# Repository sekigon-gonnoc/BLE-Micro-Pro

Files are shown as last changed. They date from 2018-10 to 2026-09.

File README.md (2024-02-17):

# BLE-Micro-Pro



BLE Micro ProはPro Microとの互換性を意識した、nrf52840モジュール搭載のブレークアウトボードです。主に自作キーボードでの使用を想定して設計しています。Pro Microを使用した自作キーボードに取り付けてQMKベースの専用ファームウェアを書き込むことで、USB/BLE5の両方に対応させることができます。  

**質問等は [Self Made Keyboard in Japan の Discord](https://discordapp.com/invite/zXCss8T) #mon-shin🔰 (トラブルシューティング) または #ble-micro-pro（開発関係の質問）チャンネルまで。**
**質問の前に過去ログを参照してください**

## 販売リンク

[BOOTH](https://nogikes.booth.pm/items/1177319)  
[遊舎工房](https://yushakobo.jp/shop/ble-micro-pro/)

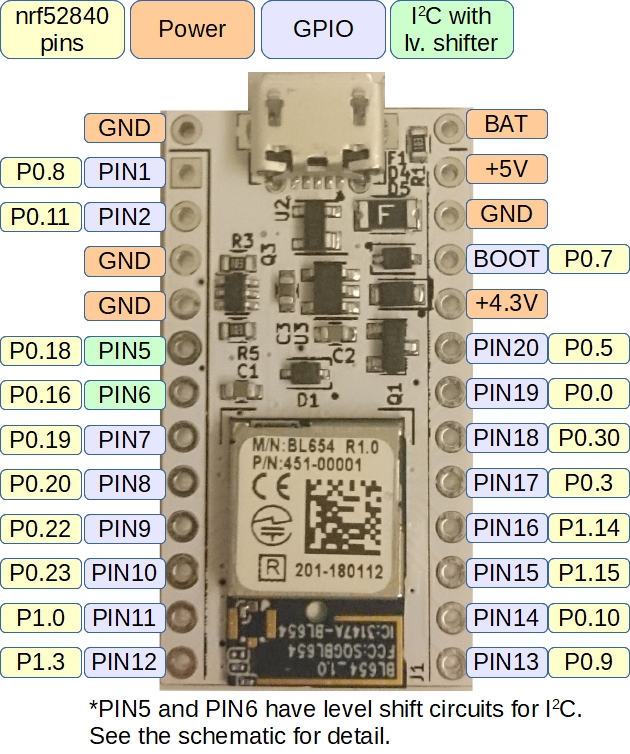
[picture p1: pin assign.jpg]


## 使用上の注意点

Pro Microとの互換性を意識して設計されていますが、以下の点にご注意ください。

- 入出力は3.3Vです。ただし、5・6番ピン(SDA・SCL)のみFETによるレベルシフト回路を実装しています。

- RAWピンの最大電圧は5Vです。

## 接続確認済みデバイス

Windows 10, Androidとの接続を確認しています。使用する機器との相性や使用環境によっては接続が不安定になることがあります。

## 使い方(ハードウェア編)

USBコネクタの横にあるBATピンから、あるいはUSBコネクタ、RAWピン、VCCピンから電源供給できます。

- BATピン (1.7V--3.6V)
- RAW, VCC (3V--5V)
  - ただし、RAW, VCC >= BAT

コンスルーに対応しているため、はんだ付けせずに基板に取り付けることも可能です。

21番ピンは5Vをダイオードで電圧降下させて4.3Vにしています。これは、WS2812などのシリアルLEDを3.3Vの信号で光らせるためです。
Helixなど24番ピンと21番ピンをショートさせているPCBの場合は、24番ピンのピンヘッダを抜き去ることでLEDが光るようになります。
LEDの電源を24番ピンからしか取っていないキーボードの場合は、はんだ付けをして21番ピンから電源を取るように改造してください。
前述のようにダイオードを挟んでいるので21・24番ピンがショートしていても壊れません。

ブートローダー書き込み済みの場合、BOOTピンをGNDに落としながら起動、あるいはファームウェアから呼び出すことでUSB経由でのファームウェアの書き込みができます。

ブートローダーを使わない場合は裏面に露出したパッドからSWDでファームウェアを書き込みます。

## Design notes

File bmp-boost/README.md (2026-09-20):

# BMP Boost

## 概要

BMP Boostは、DC-DC昇圧コンバータを搭載したnRF52開発ボードです。電池一本（0.7V以上）で動作可能で、キーボードやその他の低消費電力ワイヤレスプロジェクト向けに設計されています。

ZMK FirmwareやBLE Micro Pro用のファームウェアで動作します。

- [BOOTH](https://nogikes.booth.pm/items/1177319)
- [遊舎工房](https://shop.yushakobo.jp/products/10737)

## 特徴

- DC-DC昇圧コンバータ内蔵で電池一本（0.7V～）から動作可能
- ZMKまたはBLE Micro Pro用のQMKで動作可能
- 追加IOが必要な場合は、コンスルーのピンを差し替えて一部をハーフピッチにして拡張可能（ZMKのみ）

## ピン配置

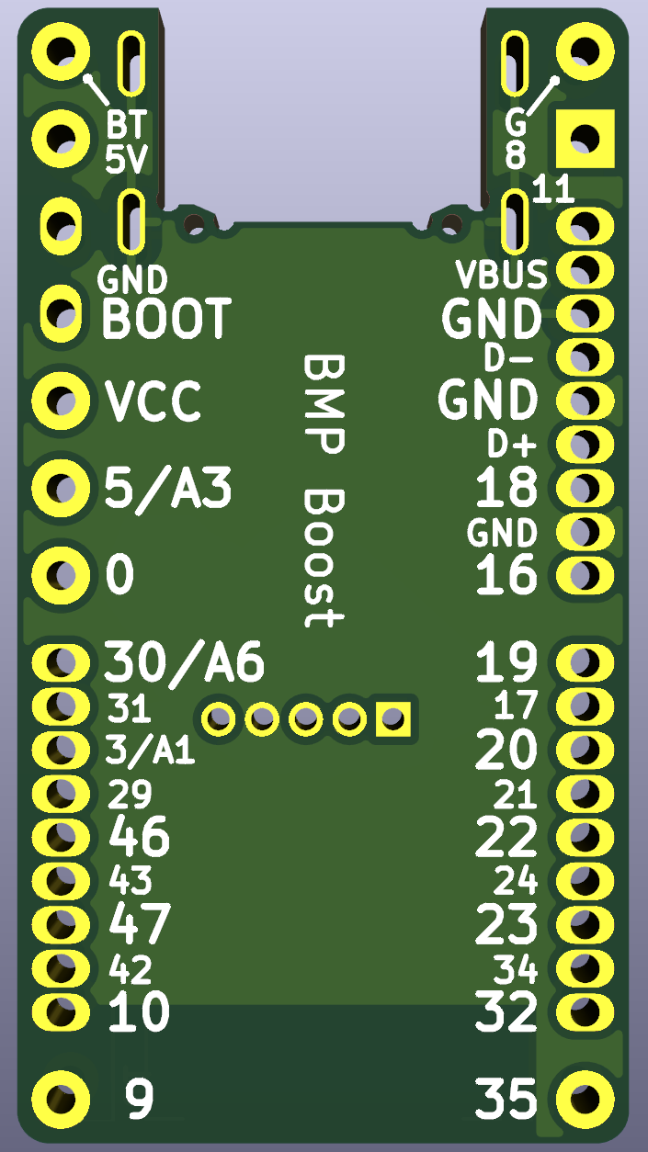
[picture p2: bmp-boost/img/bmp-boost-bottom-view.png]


### 電源コネクタ

| ラベル | 機能 |
| --- | --- |
| BT | 電源入力(0.7~3.3V)、AIN4で電圧測定可能 |
| G | 電源入力GND |

### Pro Micro互換コネクタ

| ピン番号 | ラベル | GPIO番号 | 機能 |
| --- | --- | --- | --- |
| 1 | 8 | P0.08 | GPIO |
| 2 | 11 | P0.11 | GPIO |
| 3 | GND | | GND |
| 4 | GND | | GND |
| 5 | 18 | P0.18 | GPIO |
| 6 | 16 | P0.16 | GPIO |
| 7 | 19 | P0.19 | GPIO |
| 8 | 20 | P0.20 | GPIO |
| 9 | 22 | P0.22 | GPIO |
| 10 | 23 | P0.23 | GPIO |
| 11 | 32 | P1.00 | GPIO |
| 12 | 35 | P1.03 | GPIO |
| 13 | 9 | P0.09 | GPIO |
| 14 | 10 | P0.10 | GPIO |
| 15 | 47 | P1.15 | GPIO |
| 16 | 46 | P1.14 | GPIO |
| 17 | 3/A1 | P0.03 | GPIO/AIN1 |
| 18 | 30/A6  | P0.30 | GPIO/AIN6 |
| 19 | 0 | P0.00 | GPIO |
| 20 | 5/A3 | P0.05 | GPIO/AIN3 |
| 21 | VCC | | VCC出力(約2.4V *1) |
| 22 | BOOT | | GNDに落として電源を入れるとブートローダを起動 |
| 23 | GND | | GND |
| 24 | 5V | | 電源入出力(5V) |

\*1 VCC出力にLED（WS2812など）が接続されていると消費電力が著しく増加します。
LEDを実装しないか、実装してしまっている場合はコンスルーのピンを抜いて接続しないようにしてください。
また、起動電流が大きいデバイスを接続している場合、昇圧動作がうまく始まらない場合があります。

### 追加IO

| ラベル | GPIO番号 | 機能 |
| --- | --- | --- |
| VBUS | | USB電源 |
| D- | | USBのD- |
| D+ | | USBのD+ |
| 17 | P0.17 | GPIO |
| 21 | P0.21 | GPIO |
| 24 | P0.24 | GPIO |
| 34 | P1.02 | GPIO |
| 42 | P1.10 | GPIO |
| 43 | P1.11 | GPIO |
| 29 | P0.29 | GPIO |
| 31 | P0.31 | GPIO |

## ZMK用コンポーネント

- [zmk-component-bmp-boost](https://github.com/sekigon-gonnoc/zmk-component-bmp-boost)
- [QMK用のinfo.jsonをZMK用の設定に変更するツール](https://sekigon-gonnoc.github.io/bmp-qmk-zmk-converter/)
  - 変換結果が正しいとは限らないので適宜修正してください

## 注意事項

- BMPと違いI2Cのレベル変換機能はありません。
- BMPとは電源ピン（VCC）の機能が異なります。
- 仕様等は予告なく変更となる場合があります。

## BMP Boost用拡張ボード

### bmp-boost-extender

[KiCADプロジェクトデータ](./bmp-boost-extender/)

追加IOポートを利用してBMP Boostの背面に搭載できる単四電池基板です。
オプションとしてFFC変換基板を取り付けることもできます。

|  |  |
| --- | --- |
|  |  |

#### デバイスツリーの例

オプションのFFC変換基板を使用して[paw3222センサ](https://github.com/sekigon-gonnoc/small-mouse-sensor-module)と接続する場合は下記をデバイスツリーに追加してください。

```dts
&pinctrl {
    spi0_default: spi0_default {
        group1 {
            psels = <NRF_PSEL(SPIM_SCK, 0, 17)>,
                <NRF_PSEL(SPIM_MOSI, 0, 21)>,
                <NRF_PSEL(SPIM_MISO, 0, 21)>;
        };
    };

    spi0_sleep: spi0_sleep {
        group1 {
            psels = <NRF_PSEL(SPIM_SCK, 0, 17)>,
                <NRF_PSEL(SPIM_MOSI, 0, 21)>,
                <NRF_PSEL(SPIM_MISO, 0, 21)>;
            low-power-enable;
        };
    };
}

&spi0 {
    status = "okay";
    compatible = "nordic,nrf-spim";
    pinctrl-0 = <&spi0_default>;
    pinctrl-1 = <&spi0_sleep>;
    pinctrl-names = "default", "sleep";
    cs-gpios = <&gpio0 31 GPIO_ACTIVE_LOW>;

    trackball: trackball@0 {
        status = "okay";
        compatible = "pixart,paw3222";
        reg = <0>;
        spi-max-frequency = <2000000>;
        irq-gpios = <&gpio0 29 GPIO_ACTIVE_LOW>;
        power-gpios = <&gpio0 24 (GPIO_ACTIVE_HIGH | NRF_GPIO_DRIVE_H1)>;
    };
};
```

KiCadで作成した基板の設計データは[こちら](bmp-boost-extender/)

### BMP Boost Extender Mini

[リポジトリ](https://github.com/ngsyst/bmp_boost_extender_mini)

ngsystさんが公開している小型の拡張基板です。FFCコネクタがハンダ付けされておりトラックボールやトラックパッドモジュール、エンコーダと接続可能です。

### bmp-boost-led-extender

[KiCADプロジェクトデータ](./bmp-boost-led-extender/)

緑・黄・赤の三色のLEDを追加する拡張基板です。本基板もFFCケーブルで拡張モジュールを接続できます。

#### デバイスツリーの例

[torabo-tsuki LP用のスニペット](https://github.com/sekigon-gonnoc/zmk-keyboard-torabo-tsuki-lp/tree/master/snippets/led-plus)

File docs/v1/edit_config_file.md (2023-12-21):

# 新しいキーボード用の設定を作成する

## config.jsonの説明

|キー|値|内容|
|---|---|---|
|version|3|config構造体のバージョン。 ブートローダ内の構造体の定義が変わらない限り変えない|
|pid, vid|string|16進数のPIDとVID|
|name|string||
|manufacture|string||
|rows|int|マトリクスの列数|
|cols|int|マトリクスの行数|
|device_rows|int|分割型の場合は片手分のマトリクスの列数。 一体型の場合rowsと同じにする|
|device_cols|int|分割型の場合は片手分のマトリクスの行数。 一体型の場合colsと同じにする|
|diode_direction|0~5|マトリクスの構成をあらわす。詳細は下記|
|row_pins|int array|マトリクスの行ピン。番号はPINxxに対応|
|col_pins|int array|マトリクスの列ピン。番号はPINxxに対応|
|mode|SPLIT_MASTER, SPLIT_SLAVE, SINGLE|分割マスター、分割スレーブ、一体型|
|startup|int|電源が入ったタイミングでBLEのアドバタイズを実行するかどうか。 [0]は実行しない、[1]で実行する。|
|led->pin|int array|LED(ws2812系)のピン。番号はPINxxに対応|
|led->num|int|LEDの数|
|reserved|uint8_t[8]|予約領域。現時点では[1]はインジケータLEDのピン設定、[2]はオートスリープの時間設定に使用|

### 通信間隔の設定

無線接続時に遅延を感じる場合はperipheral, centralの max_interval, min_intervalを小さくしてください。最小値は10msで、5ms刻みで変更できます  
また、OSのBLEに関する省電力設定も確認してみてください

### マトリクスの構成

#### diode_direction
 
|数値|構成|説明
|---|---|---|
|0|COL2ROW|QMKと同じ|
|1|ROW2COL|QMKと同じ|
|2|COL2ROW with LPME|master側がCOL2ROWでスレーブ側にはLPMEを搭載|
|3|ROW2COL with LPME|master側がROW2COLでスレーブ側にはLPMEを搭載|
|4|COL2ROW2COL|duplex-matrix。COL2ROWでスキャンしたあとROW2COLでスキャンする。modeがSINGLEのときのみ対応|
|5|ROW2COL2ROW|duplex-matrix。ROW2COLでスキャンしたあとCOL2ROWでスキャンする。modeがSINGLEのときのみ対応|

#### row_pins, col_pins
  -  COL2ROW, ROW2COLの場合: 通常のマトリクスの設定。device_rows/colsに指定したのと同じ数だけピンを設定する
  -  with LPMEの場合: LPMEを使ったマトリクスの設定。BLE Micro Proが制御するマトリクスのピン設定に続けて、LPMEが制御するマトリクスのピン設定を書く。合計でrows/colsに設定したのと同じ数だけピンを設定する
  -  duplex matrixの場合: 最初にスキャンする方向に合わせてrow_pins, col_pinsを設定する。device_rows, device_colsにはrow_pins, col_pinsの要素数を指定する。rowsにはdevice_rowsの2倍の値を、colsにはdevice_colsと同じ値を設定する



### オートスリープ

電池駆動時に一定時間無入力の状態が続くと自動的にスリープします。

スリープまでの時間は`config.reserve[2]*10min`です。

オートスリープを無効にするには`reserve[2]`に0を指定してください。

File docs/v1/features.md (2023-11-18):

# 特徴/機能一覧

## USB/BLEでの接続
- BLE Micro Proを1台使用した一体型キーボードの完全無線化
  - Naked60BMPのような一体型キーボードの場合、Pro MicroをBLE Micro Proに置き換えることで無線化できます
  - 消費電力はマスター側で\~100uAで、300mAhの電池を使うと3000時間もつ計算です

- BLE Micro Proを2台使用した分割キーボードの完全無線化
  - HelixやErgo42のような分割型の自作キーボードを完全無線化できます
  - 消費電力はマスター側で\~300uA、スレーブ側で\~100uA程度で、300mAhの電池を使うと1000時間もつ計算です

- BLE Micro ProとLPME-IOを使用した部分無線化
  - 分割キーボードの片方にBLE Micro Proを、もう一方にLPME-IOを搭載することで左右の通信は有線、デバイスとの通信は無線という構成が実現できます
    - LPME-IOを使用するにはキーボード基板がI2Cによる左右の通信に対応している必要があります 

## プログラミングレスでのファームウェア更新・設定変更・キーマップ書き換え
  - BLE Micro Proをパソコンに接続するとUSBドライブとして認識され、設定ファイルを書き込むことでキーボードの設定やキーマップを書きかえることができます。そのため、取り付けるキーボードを変えたりキーマップを変えたりするときにプログラミングしなおす必要がありません。
  - キーマップはRemap, Vialを使って変更できます。Vialを使うことでTapping Termなどの設定を変更したり、コンボ・タップダンス・オーバーライドを設定することもできます
  - ブートローダー起動時もUSBドライブとして認識され、ファームウェアをドラッグアンドドロップすることでアップデートできます
  - セキュリティの都合等でUSBドライブとして認識されると困る場合には機能を無効化できます

## その他

- 穴径がコンスルーに対応しているため、コンスルーを使う場合はハンダ付け不要
- BLEの接続状況を示すためのインジケータLED（ディスクリートのLEDによる）
- 無線接続中、一定時間の間に入力がないと自動的に省電力モードに移行（無効化可）

## QMKの機能対応状況
|機能|対応|補足|
|--|--|--|
|キーボード|✔|
|マウス|✔|
|System/Consumer(音量など)|✔|
|エンコーダ|✔|
|VIA(Remap)|✔||
|VIAL|✔||
|Console|✔|HIDではなくシリアルポートによる実装。print/dprintに加えて[CLI](cli.md)を提供|
|Raw|✔|
|LED|✔|USB電源駆動時のみ。左右同期も実装済み|
|OLED|✔|
|eeprom|✔||
|SPI|✔|
|I2C|✔|
|Analog|✔|17,18,20番ピンのみ|
|Audio|❌|
|NKRO|❌|
|PS/2|❌|
|USART|❌|

## ハードウェア仕様

### 電源
以下の二系統から供給可能。RAW, VCCからの供給がBATより優先される
  - BAT (1.7V--3.6V)
  - RAW or VCC (3V--5V)
    - ただし、RAW, VCC >= BATのときのみ

### 入出力
  - 電源電圧か3.3Vの低い方 (**5Vトレラントではありません**)
  - 5・6番ピン(Pro MicroのSDA・SCL)のみFETによるレベルシフト回路を実装

### 接続確認済みデバイス

- Windows, Androidとの接続を確認しています。ただし、使用するbluetoothアダプタによっては接続が不安定になることがあります。

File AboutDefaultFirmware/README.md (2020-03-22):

# BLE Micro Pro 標準ファームウェア (beta版)

## 特徴
 キーボードやキーマップごとにファームウェアをビルドし直すのではなく、マトリクスの構造やキーマップといった情報をBLE Micro Pro上のファイルを編集して変更します

 BLE Micro Proをパソコンに繋ぐとマスストレージデバイスとして認識され、設定ファイルを編集できます

 キーマップの書き換えには[QMK Configurator](https://config.qmk.fm)が生成したjsonファイルも使用できます

 
 
## 制約 
 defineで切り替えるタイプのQMKの設定を変更したい場合や、キーマップにカスタムキーコードなどを追加したい場合はファームウェアのビルド/書き込みが必要です

 その場合でもビルド環境の用意は以前より簡単になっています

## 使い方 
- [Getting started](doc/getting_started.md)
- [ビルド方法](doc/build_bmp_qmk_firmware.md)
- [Command Line Interface](doc/cli.md)
- [キーボード開発者向け情報](doc/define_new_keyboard.md)

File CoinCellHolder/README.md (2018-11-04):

# CR1632基板キット

CR1632を二個のせられます。並列的に繋いでいるので、1個の電池のみで動かすことも出来ます。

## 組み立て上の注意点

- コイン電池ホルダの突起を基板側のシルクに合わせる

- 電池ホルダ間のクリアランスが狭いのでショートしないようにする
- 電池ホルダの足を折り曲げると背が低くなる
- ダイオードの向きに注意(ダイオードのカソード(ラインが入ってるほう)がシルクのマーク側)
- 電源出力のマイナス側は出っ張らないようにする(電池の取り付け・取り外しができなくなる)
- 他の基板と接触する部分(作例だと裏面)はテープなどで絶縁する







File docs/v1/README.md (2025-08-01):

# BLE Micro Pro

BLE Micro ProはPro Microとの互換性を意識した、nrf52840モジュール搭載のブレークアウトボードです。主に自作キーボードでの使用を想定して設計しています。Pro Microを使用した自作キーボードに取り付けてQMKベースの専用ファームウェアを書き込むことで、USB/BLE5の両方に対応させることができます。  

**こちらは最新版ファームウェア(v1)の説明です。最新版では設定ファイルの形式が変更になりました。Vialにも対応しています。**

**BMP BoostのハードウェアやZMKで使用する方法については[こちら](https://github.com/sekigon-gonnoc/BLE-Micro-Pro/tree/master/bmp-boost)をご確認ください。**

[QMK用のinfo.jsonをZMK用の設定に変更するツール](https://sekigon-gonnoc.github.io/bmp-qmk-zmk-converter/)
  - 変換結果が正しいとは限らないので適宜修正してください

## 販売リンク

[BOOTH](https://nogikes.booth.pm/items/1177319)  
[遊舎工房](https://yushakobo.jp/shop/ble-micro-pro/)

## 特徴

- BLEでの無線接続
  - BLE Micro Proを2台使用した分割キーボードの完全無線化
  - BLE Micro ProとLPME-IOを使用した部分無線化
- USBでの有線接続
- プログラミングレスでのファームウェア更新・設定変更・キーマップ書き換え

## スタートガイド

- [買ってきた自作キーボードキットを無線化したい](getting_started.md)
  - 遊舎工房やBOOTHで購入したキットを無線化する場合はこちら
  - Pro Microを使用しているキットを無線化できます
- [BLE Micro Proに対応したキーボードを設計したい](design_guide.md)
  - 自分でキーボードを設計するときの注意点などをまとめています

## 困ったときは

- [よくある質問](FAQ.md)
- そのほかの質問等は [Self Made Keyboard in Japan の Discord](https://discordapp.com/invite/zXCss8T)
#mon-shin🔰 (トラブルシューティング) または #ble-micro-pro（開発関係の質問）チャンネルまで。過去ログを検索すると役立つ情報があるかもしれません。

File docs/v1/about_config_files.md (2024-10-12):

# 設定について

- [BLE Miro Proを更新して設定ファイルを書き込む手順](#ble-miro-proを更新して設定ファイルを書き込む手順)
  - [bmp-vial対応の設定ファイルを用意する](#bmp-vial対応の設定ファイルを用意する)
  - [BLE Micro Proに設定ファイルを書き込む](#ble-micro-proに設定ファイルを書き込む)
- [BLE Miro Pro Web Configuratorに登録するための手順](#ble-miro-pro-web-configuratorに登録するための手順)
  - [vial.jsonとconfig.jsonの用意](#vialjsonとconfigjsonの用意)
  - [デフォルトキーマップ用binファイルを用意する](#デフォルトキーマップ用binファイルを用意する)
  - [2種類のjsonファイルとデフォルトキーマップ用binファイルを登録する](#2種類のjsonファイルとデフォルトキーマップ用binファイルを登録する)

## BLE Miro Proを更新して設定ファイルを書き込む手順

### bmp-vial対応の設定ファイルを用意する

設定ファイルは2種類のjsonファイルと、jsonから生成される1つのbinファイルがあります。
これらの設定ファイルは[bmp-vial-config-generator](https://sekigon-gonnoc.github.io/bmp-vial-config-generator/)を利用することでQMKのinfo.jsonから変換できます。そのため、すでにPro Micro用のファームウェアが用意されていれば、単純な変換作業のみでBLE Micro Pro用の設定も用意できます。

* vial用jsonファイル(vial.json)
  * vial用の設定ファイルです
* config用jsonファイル(config.json)
  * BLE Micro Pro用の設定ファイルです。従来とは一部の項目が変わっています
* 書き込み用binファイル(config.bin)
  * vial.jsonとconfig.jsonから生成された書き込み用のバイナリファイルです

1. 左側のテキストボックスにQMKのinfo.jsonを記入する
   1. QMK公式のリポジトリにinfo.jsonが存在する場合はテキストボックス下部にあるリストから選択できます。
   1. info.jsonの中にはmatrixのピンと配置の情報が必要です。これらの情報がconfig.hやLAYOUTマクロに記入されている古いファームウェアでは`qmk info -kb <keyboard> -f json`コマンドを使用するとinfo.jsonを生成できる場合があります。
2. 左下の`Generate`ボタンをクリックしてvial.jsonとconfig.jsonを生成する
   1. 自動生成されたvial.jsonでは内容が不十分な場合はテキストボックスの中身を書き換えてください
3. 中央下の`Append BMP custom keycodes`ボタンをクリックして、BLE Micro Pro用のカスタムキーコードリストをvial.jsonに追加する
4. 分割キーボードの場合は右下のリストからconfig.jsonの対象(master, slave, lpme)を選択する
   1. 自動生成されたconfig.jsonでは内容が不十分な場合はテキストボックスの中身を書き換えてください。通常のマトリクスであればinfo.jsonからの自動変換で十分な場合が多いですが、duplex-matrixは修正が必要な場合があります。→[config.jsonの説明](edit_config_file.md)
5. `Download config.bin`ボタンをクリックしてconfig.binを生成・ダウンロードする

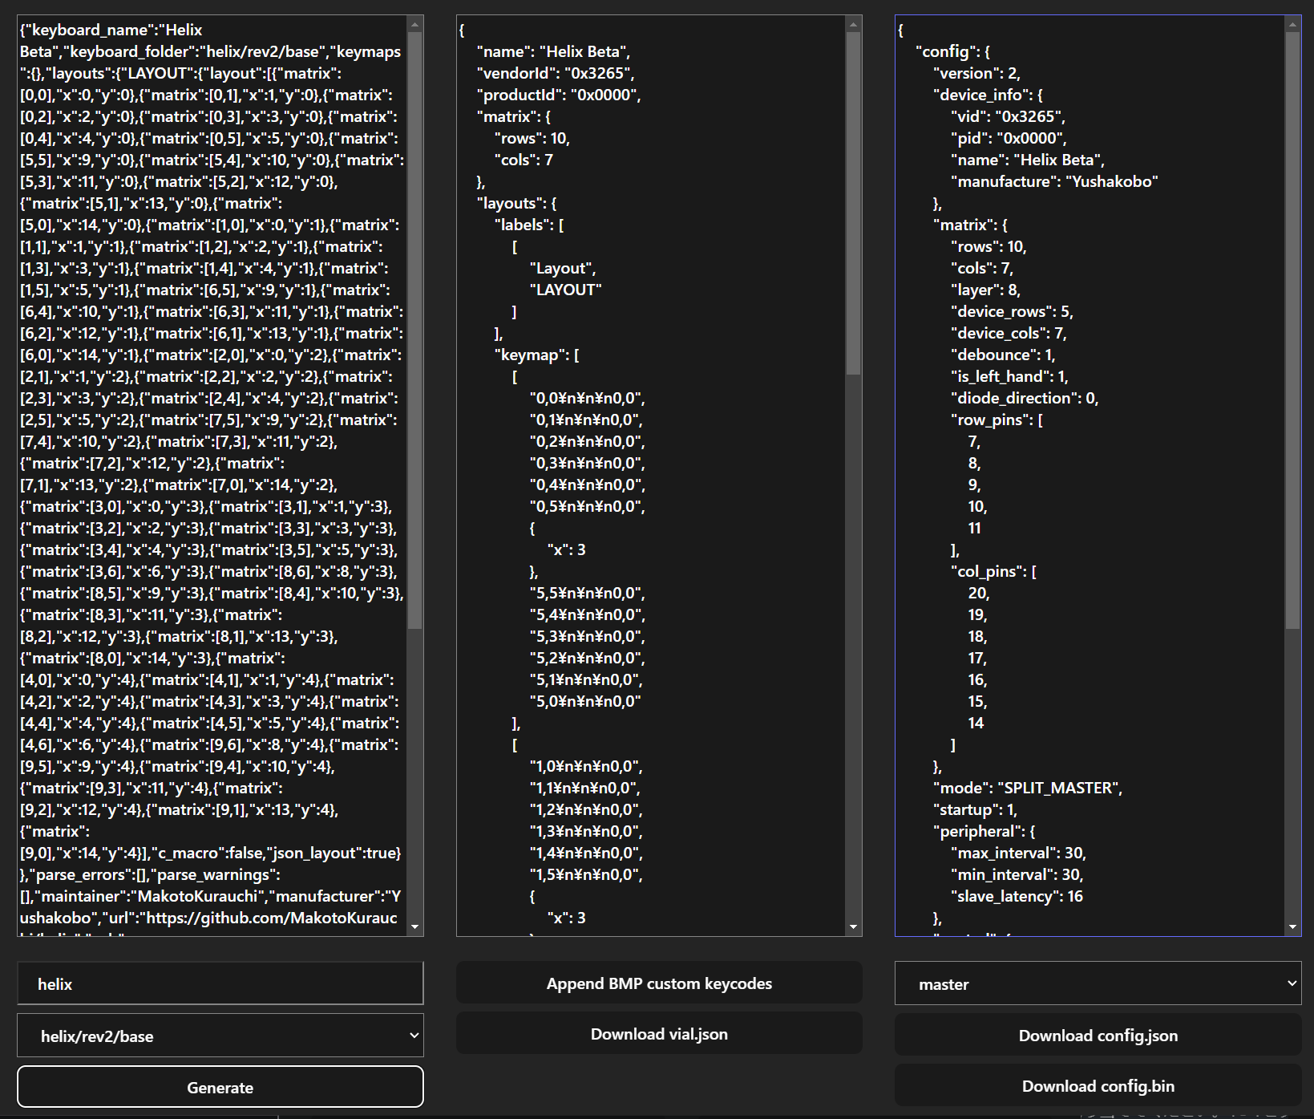
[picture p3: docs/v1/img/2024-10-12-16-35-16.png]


### BLE Micro Proに設定ファイルを書き込む 

マスストレージ経由で書き込む場合は下記の手順で作業してください。

1. BLE Micro Proのアプリケーションが起動していることを確認する
   1. マスストレージとして認識されているBLE Miro Proを開き、中にCONFIG.BINがあることを確認する
2. 用意したconfig.binをドラッグアンドドロップして書き込む（ファイル名は任意）
3. 書き込み完了後に電源を再投入して、デバイス名が書き込んだキーボードに変わっていることを確認する

[BLE Micro Pro Web Configurator](https://sekigon-gonnoc.github.io/BLE-Micro-Pro-WebConfigurator/)から設定を書き込むこともできます。

* `Edit config`メニューを選択してください。
* キーボードリストから`Upload your own`を選択してください。
* `Update`をクリックするとファイルダイアログが表示されます。作成したbinファイルを選択してください。
* USBデバイスへのアクセスを求めるポップアップが表示されます。
* キーボードを選択して`接続`をクリックすると書き込みが始まります。
  * どのデバイスがBLE Micro Proか分からない場合はUSBケーブルを抜き差ししてデバイス一覧の変化を確認してください。
  * ポップアップにキーボードが表示されない場合はファームウェアの書き込みができていないので、最初のステップからリトライしてください。
* 書き込みが成功したら次のステップに進んでください。
  * 数十秒待っても書き込みが完了しなかったらブラウザをリロードしてUSBケーブルを抜き差してからリトライしてください。

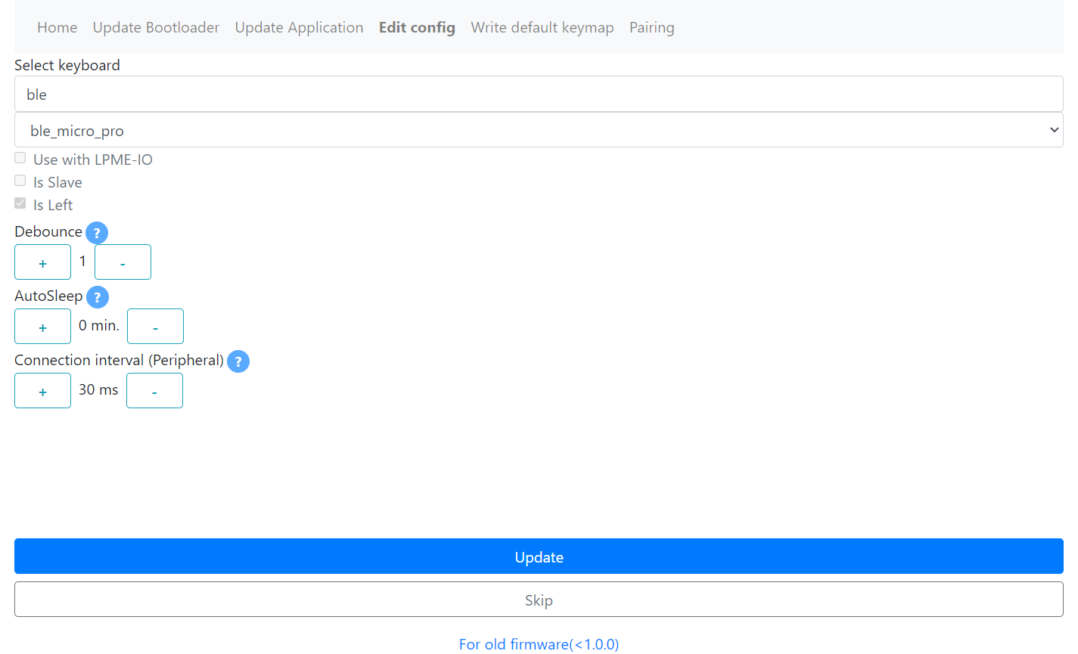
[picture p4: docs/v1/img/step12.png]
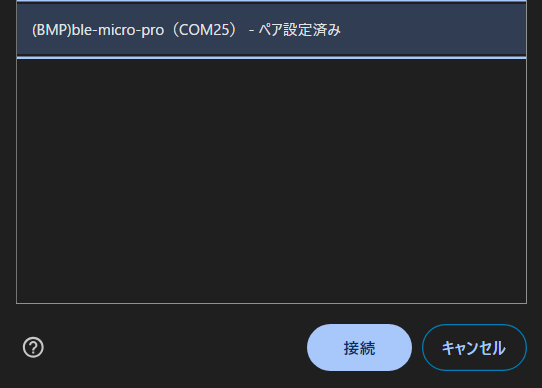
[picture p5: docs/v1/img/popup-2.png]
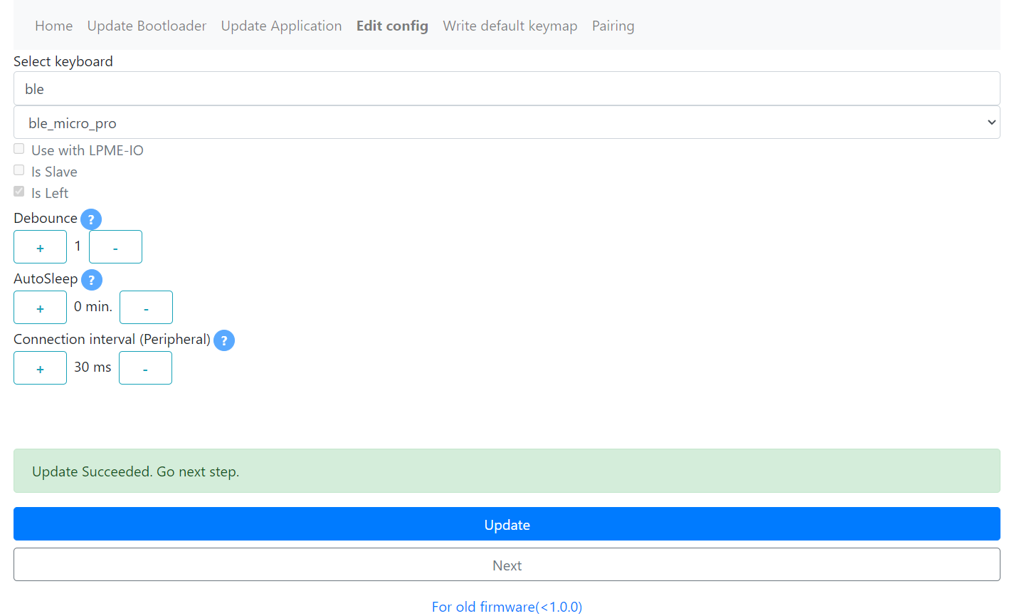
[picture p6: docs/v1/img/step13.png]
|  |  |  |
| --- | --- | --- |

## BLE Miro Pro Web Configuratorに登録するための手順

Vial対応の設定ファイルをBLE Micro Pro Web Configuratorに登録したい方は追加で以下の手順の実施をお願いします。該当キーボードの作者以外の方でもプルリクエストを作成していただいて構いません。

1. [bmp-vial-config-generator](https://sekigon-gonnoc.github.io/bmp-vial-config-generator/)でvial.jsonとconfig.jsonを生成し、ダウンロードする
1. (任意)デフォルトキーマップ用binファイルを用意する
1. 2種類のjsonファイルとデフォルトキーマップ用binファイルを[bmp-vial-config/](https://github.com/sekigon-gonnoc/BLE-Micro-Pro/tree/master/bmp-vial-config)フォルダに保存し、プルリクエストを作成する

### vial.jsonとconfig.jsonの用意

[bmp-vial-config-generator](https://sekigon-gonnoc.github.io/bmp-vial-config-generator/)で設定を作成したら、それぞれの列の下部にある`Download *.json`ボタンをクリックして各jsonファイルをダウンロードしてください。

### デフォルトキーマップ用binファイルを用意する

EEPROMリセット時に反映されるデフォルトキーマップの設定ファイルを用意してください。

1. RemapまたはVialを使ってデフォルトにしたいキーマップをキーボードに書き込む
2. BLE Micro Proのマスストレージを開きEEPROM.BINをPCにコピーする
3. コピーしたEEPROM.BINの名前を変更する
   1. 名前はキーボード設定用のconfig.binに合わせて`<キーボード名>_default.bin`としてください
4. ファイルをBLE Micro Proに書き戻し、EEPROMをリセットしたときに意図通りのキーマップになっていることを確認する

### 2種類のjsonファイルとデフォルトキーマップ用binファイルを登録する

BLE Miro Proのリポジトリの [bmp-vial-config/](https://github.com/sekigon-gonnoc/BLE-Micro-Pro/tree/master/bmp-vial-config)フォルダにvial.json, config.json, default.binファイルを追加してプルリクエストを作成してください。

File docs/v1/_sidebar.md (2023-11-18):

* [はじめに](/)
  * [特徴/機能一覧](features.md)
  * [自作キーボードキットを無線化する](getting_started.md)
  * [無線対応の自作キーボードを設計する](design_guide.md)

* [設定について](about_config_files.md)

* [発展編](advanced.md)
  * [ファームウェアをビルドする](build_firmware.md)
  * [CLIから操作する](cli.md)
  * [セーフモードについて](safemode.md)

* [FAQ](FAQ.md)

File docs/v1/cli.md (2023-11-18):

# CLI

BLE Micro Proに各種のコマンドを命令したり、デバッグメッセージを確認したりできます。

BLE Micro ProのCLIを開くにはTeraTerm・screen・cuなどからシリアルポートを開いてください。

| command | description |
| --- | --- |
| reset | Reset system |
| adv | Start advertising |
| dfu | Jump to bootloader |
| show | Show bonded devices |
| del | Delete bond information |
| help | Show this message |

## adv `<id>`

 id番目のペアリング済みデバイスに向けてアドバタイズを開始します。分割マスター設定の場合、スレーブデバイスのスキャンも開始します。idを指定しない場合はペアリングしていないデバイスも含めすべてのデバイスに向けてアドバタイズを開始します。  
 ペアリング済みデバイス一覧はshowコマンドで確認できます

## show

BLEのペアリング状況(ID, role, MAC)を表示します。

## del `<id>`

id番のデバイスとのペアリングを削除します。別途相手デバイス側に残っているペアリング情報も削除してください  
idを指定しない場合すべてのペアリング情報を削除します

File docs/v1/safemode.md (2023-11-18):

# セーフモードについて

CONFIG.BINの中身が間違っている場合などにBLE Micro Proがセーフモードとして起動することがあります。発生要因は以下のとおりです。

- CONFIG.BINの中身が間違っている
- `BMP_FORCE_SAFE_MODE`フラグを有効にしたファームウェアを書き込んだ
- BLE Micro Pro内部でエラーが一定回数以上発生した

セーフモードで起動すると書き込んだCONFIG.BINの代わりにファームウェアに埋め込まれたデフォルトの設定が使用されます。

セーフモードで起動しているかどうかは[CLI](cli.md)に繋いだときの表示名がキーボード名か、safemodeになっているかで判別できます。

セーフモードから復帰するには一度リセットまたは電源再投入してください。

何度リセットしてもセーフモードになる場合、CONFIG.BINの中身が間違っている可能性があるため、中身を確認して書き換えてください。

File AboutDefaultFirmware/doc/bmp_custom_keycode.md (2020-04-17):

[ドキュメントサイトに移転しました](https://sekigon-gonnoc.github.io/BLE-Micro-Pro)

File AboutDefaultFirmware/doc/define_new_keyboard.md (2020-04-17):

[ドキュメントサイトに移転しました](https://sekigon-gonnoc.github.io/BLE-Micro-Pro)

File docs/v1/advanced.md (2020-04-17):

# 発展編

ファームウェアに機能を追加するために自分でビルドする方法や、トラブル時に役立つ情報をまとめます。

- [ファームウェアをビルドする](build_firmware.md)
- [CLIから操作する](cli.md)
- [セーフモードについて](safemode.md)

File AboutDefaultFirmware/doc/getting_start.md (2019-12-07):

# Getting start
- [Getting start](#getting-start)
  - [ブートローダ・アプリケーションのアップデート](#ブートローダアプリケーションのアップデート)
    - [ブートローダの起動](#ブートローダの起動)
    - [uf2を使ったアップデート](#uf2を使ったアップデート)
    - [nrfutilを使ったアップデート](#nrfutilを使ったアップデート)
      - [nrfutilの準備](#nrfutilの準備)
      - [アップデートの実行](#アップデートの実行)
  - [config.jsonの書き込み](#configjsonの書き込み)
  - [keymap.jsonの設定](#keymapjsonの設定)
  - [tapping_term.jsonの設定](#tapping_termjsonの設定)
  - [config.jsonの設定 (一般ユーザ向け)](#configjsonの設定-一般ユーザ向け)
    - [開発者向け情報](#開発者向け情報)
  - [設定ファイルのアップデート](#設定ファイルのアップデート)
  - [設定ファイルの削除](#設定ファイルの削除)

## ブートローダ・アプリケーションのアップデート
BLE Micro Proはブートローダとアプリケーションファームウェアがセットになって動作します

- アップデートする場合ブートローダとアプリケーションのメジャーバージョン・マイナバージョンを一致させてください。バージョン番号の表記は下記のとおりです。
  ```
    version number: <major>.<minor>.<revision>
  ```

- アップデートはブートローダ -> アプリケーションの順に行ってください。また、アプリケーションをアップデートする前にKEYMAP.JSNなどの設定ファイルのバックアップを取ってください

- [ブートローダ](https://github.com/sekigon-gonnoc/BLE-Micro-Pro/releases)と[コンパイル済みアプリケーション](https://github.com/sekigon-gonnoc/qmk_firmware/releases)はReleaseページから入手できます。  
  - コンパイル済みアプリケーションにはQMKのビルドオプションとしてTAPPING_TERM_PER_KEY, PERMISSIVE_HOLD などが設定してあります。  
  - 最新版のファームウェアを使いたい場合、自分の好きなオプションを設定したい場合やカスタムキーコードを設定したい場合は[自分でビルドする](build_bmp_qmk_firmware.md)必要があります。  
 
### ブートローダの起動
- キーボードのリセットボタンを押しながらUSB接続するとブートローダが起動します

- 既にキーボードとして動作する場合には[CLI](cli.md)からdfuコマンドを送信することでも起動できます  

- v0.4.0以降のQMK for BMPを使用している場合、起動中にリセットスイッチ長押しでも起動します

- v0.2以降のブートローダとそれ以前ではアップデート方法が異なります。バージョンに応じた手順でファームウェアとブートローダをアップデートしてください

  - [マスストレージデバイスとして認識される場合](#uf2を使ったアップデート)

  - [マスストレージデバイスとして認識されないが、シリアルポートとしては認識される場合](#nrfutilを使ったアップデート)
    - どのポートがBLE Micro Proかわからない場合は、起動前後のシリアルポート一覧を比較してください

### uf2を使ったアップデート
拡張子が`.uf2`のファイルを使って書き込みます  
**[ブートローダーv0.2.0, v0.3.0からアップデートする場合はv0.2.1, v0.3.1を経由してください](https://github.com/sekigon-gonnoc/BLE-Micro-Pro/issues/10)**  
nrfutilを使う場合は経由せずに直接アップデートできます

- BLE Micro Proがマスストレージデバイスとして認識され、中に`INFO_UF2.TXT`があることを確認してください。このファイルがない場合、ブートローダの起動に失敗しているので再起動してください
  - v0.4.0以降、ブートローダ起動時のボリュームラベルはBLEMICROPRO、キーボード起動時のボリュームラベルは設定したキーボード名になるので、これで判別することもできます

- アップデートしたいuf2ファイルをコピーするとアップデートが始まります。アップデート中はケーブルを外さないでください

- アップデートが完了すると自動でアンマウントされます

- ブートローダをアップデートした場合、`INFO_UF2.TXT`を開いてアップデート完了を確認してください

- アプリケーションのアップデートの場合は`VERSION.TXT`を開いてアップデート完了を確認してください

ブートローダ、アプリケーションのアップデートが完了したら次の手順は[config.jsonの書き込み](#configjsonの書き込み)です

### nrfutilを使ったアップデート
拡張子が`.zip`のファイルを使って書き込みます

#### nrfutilの準備
書き込みソフトである[nrfutil](https://github.com/NordicSemiconductor/pc-nrfutil)を用意します。

- Windowsの場合  
    nrfutil.exeを[ダウンロード](https://github.com/NordicSemiconductor/pc-nrfutil/releases)してください

- Linux, Macの場合  
    pipでnrfutilをインストールしてください。以前はpython2.x向けでしたが現在はpython3系で動作するようです。
    ```
      pip install --user nrfutil
    ```

#### アップデートの実行
- キーボードのリセットボタンを押しながらUSB接続、またはターミナルソフトからdfuコマンドを送信してから以下を実行します。パッケージ名、ポート名は状況に応じて書き換えてください  
    ```
   nrfutil dfu usb-serial -pkg <パッケージ名>.zip -p <ポート名>
    ```
 
## config.jsonの書き込み
 - BLE Micro ProをPC等にUSBで接続するとマスストレージデバイスとして認識されます  
   アプリケーションが起動している場合は`KEYMAP.JSN`や`CONFIG.JSN`といったファイルが確認できます

 - 使いたいキーボードのconfig.jsonをコピーしてください。[keyboards](../keyboards)フォルダに使いたいキーボードがない場合は[スクリプトを使ってQMKから生成](define_new_keyboard.md)できます

 - コピー完了後、BLE Micro Proを再起動してください

## keymap.jsonの設定
 - [QMK Configurator](https://config.qmk.fm)で生成したkeymap.jsonをそのまま読み込むことができます。

 - keymap.json, tapping_term.jsonは即時反映されるので再起動は必要ありません

 - 認識できる KC_XX はQMK Configurator準拠です  
    `"KC_EXLM", "KC_AT", "KC_HASH"`

 - 書き込み時にはKC_を付けなくても認識されます。読み出し時には自動でKC_が付きます  
    `"KC_A", "A", "a"` 

 - !, @, # などの記号をそのまま書き込むこともできます。`\`, `"` を設定するときはエスケープしてください。  
    `"!", "@", "#", "\\", "\""`

 - USキーボードとJPキーボードでキーコードが違う記号を書き込んだ場合にどちらで解釈されるかはconfig.jsonの設定によります。（例: "@"： USのとき-> KC_AT, JPのとき -> JP_AT) 

 - カスタムキーコードとして[BLE Micro Pro固有のキーコード](bmp_custom_keycode.md)にも対応しています 

 - 自分でファームウェアをビルドしてカスタムキーコードを設定した場合でも辞書を定義しておけば認識できます。ANY(1255)などして数値で直接指定する方法もあります。
 
## tapping_term.jsonの設定
 - get_tapping_term()で返すキーコードとタッピングタームのペアを設定します
 - デフォルトのタッピングタームはKC_NOに設定します
 - KC_NOは一番最後に設定してください
  ```
  {"tapping_term":{
        "LT(1,KC_A)":300,  
        "KC_NO":200,
        }}
  ```

## config.jsonの設定 (一般ユーザ向け)
|キー|値|内容|
|---|---|---|
|debounce|1 ~|debounceの設定。1増やすと17ms伸びる|
|is_left_hand|0 or 1|左手用のとき1|
|mode|SPLIT_MASTER, SPLIT_SLAVE, SINGLE|分割マスター、分割スレーブ、一体型|
|startup|0 or 1|起動時に自動でアドバタイズを開始する場合は1|
|locale|US or JP|英語キーボード or 日本語キーボード|
|use_ascii|0 or 1| 1の場合keymap.jsonの表示内容がQMK準拠ではなく記号になる.<br> 例) KC_EXLM -> KC_!|
|peripheral||マスター、一体型の場合: PC等との接続に使われる設定<br>スレーブの場合: マスターとの接続に使われる設定|
|cetral||マスターの場合のみ: スレーブとの接続に使われる設定|

無線接続時に遅延を感じる場合は peripheral, central の max_interval, min_interval を小さくしてください。最小値は10msで、5ms刻みで変更できます  
また、OSのBLEに関する省電力設定も確認してみてください

### [開発者向け情報](define_new_keyboard.md)

## 設定ファイルのアップデート
  BLE Micro Pro上のファイルを直接編集することもできますが、バックアップの意味も兼ねて一度PC上にコピーしてから編集、転送することを推奨します。
  
## 設定ファイルの削除
  PCから見えているファイルを削除してもBLE Micro Proを再起動すると復活します。完全に削除してデフォルトに戻したい場合は[CLI](cli.md)からremoveコマンドを使ってください。

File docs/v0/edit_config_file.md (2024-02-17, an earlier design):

# 新しいキーボード用の設定を作成する

**このページは旧バージョンのファームウェアについての説明です。最新版ファームウェアの説明は[こちら](../v1/README.md)**

## QMK用の設定から変換する

Pro Micro用のQMKがすでにある場合はその設定を利用してBLE Micro Pro向けの`config.json`を生成できます。
ベースとなるQMKのバージョンに応じて下記のいずれかの方法を使用してください

### QMK公式にマージざれている場合

https://sekigon-gonnoc.github.io/ble-micro-pro-config-generator/

でkeyboardとlayoutを選択してconvertボタンをクリックすると設定が生成されます。

### info.jsonに各種設定を用意している場合

https://sekigon-gonnoc.github.io/ble-micro-pro-config-generator/

のテキストボックスにinfo.jsonの中身を貼り付けて、検出されたlayoutを選択してconvertボタンをクリックすると設定が生成されます。

### config.hに各種設定を用意している場合

[変換スクリプト](https://github.com/sekigon-gonnoc/BLE-Micro-Pro/blob/master/AboutDefaultFirmware/keyboards/config_converter.py)を用いて`config.json`を生成できます。

```
./keyboards/config_converter.py ~/qmk_firmware/helix/rev2
```

LAYOUTマクロなどが複数定義されている場合は検出されたレイアウトの一覧が表示されるので、使いたい定義を選択してください。

## config.jsonの説明

- 設定例についてはリポジトリを参照してください

|キー|値|内容|
|---|---|---|
|version|2|config構造体のバージョン。 ブートローダ内の構造体の定義が変わらない限り変えない|
|pid, vid|string|16進数のPIDとVID|
|name|string||
|manufacture|string||
|description|string||
|rows|int|マトリクスの列数|
|cols|int|マトリクスの行数|
|device_rows|int|分割型の場合は片手分のマトリクスの列数。 一体型の場合rowsと同じにする|
|device_cols|int|分割型の場合は片手分のマトリクスの行数。 一体型の場合colsと同じにする|
|diode_direction|0~5|マトリクスの構成をあらわす。詳細は下記|
|row_pins|int array|マトリクスの行ピン。番号はPINxxに対応|
|col_pins|int array|マトリクスの列ピン。番号はPINxxに対応|
|layout|int array|qmkのレイアウトマクロに対応するもの。詳細は後述|
|mode|SPLIT_MASTER, SPLIT_SLAVE, SINGLE|分割マスター、分割スレーブ、一体型|
|startup|int|電源が入ったタイミングでBLEのアドバタイズを実行するかどうか。 [0]は実行しない、[1]で実行する。|
|led->pin|int array|LED(ws2812系)のピン。番号はPINxxに対応|
|led->num|int|LEDの数|
|keymap->locale|"US" or "JP"|USキーボードとして接続するか、JPキーボードとして接続するかの設定。keymap.jsonの変換・表示の挙動に影響|
|reserved|uint8_t[8]|予約領域。現時点では[0]はKugel用の設定、[1]はインジケータLEDのピン設定、[2]はオートスリープの時間設定に使用|

### 通信間隔の設定

無線接続時に遅延を感じる場合はperipheral, centralの max_interval, min_intervalを小さくしてください。最小値は10msで、5ms刻みで変更できます  
また、OSのBLEに関する省電力設定も確認してみてください

### マトリクスの構成

- diode_direction
 
|数値|構成
|---|---
|0|COL2ROW
|1|ROW2COL
|2|COL2ROW with LPME
|3|ROW2COL with LPME
|4|COL2ROW2COL
|5|ROW2COL2ROW

- row_pins, col_pins
  -  COL2ROW, ROW2COLの場合: 通常のマトリクスの設定。device_rows/colsに指定したのと同じ数だけピンを設定する
  -  with LPMEの場合: LPMEを使ったマトリクスの設定。BLE Micro Proが制御するマトリクスのピン設定に続けて、LPMEが制御するマトリクスのピン設定を書く。合計でrows/colsに設定したのと同じ数だけピンを設定する
  -  duplex matrixの場合: 通常のマトリクスと同じ設定を書く。

### layoutの設定

layout配列の数値はキーマトリクスの行->列の順に1から降った番号に対応し、対応する位置にあるキーマップとスイッチの対応を表しています。分割型の場合は左のマトリクスから順に数値を割当てます。

ただし、0は列の区切りを表します。

例えば次のようにマトリクスが配置された左右分割キーボードがあったとき

```
+------+-----+                +-----+-----+
 (1,0) |(1,1)|                |(1,1)|(1,0)|
+------+-----+-----+    +-----+-----+-----+
 (0,0) |(0,1)|(0,2)|    |(0,2)|(0,1)|(0,0)|
+------+-----+-----+    +-----+-----+-----+
```

左手の(0,0)が1, そのまま2,3,4,5と続いて6は存在せず、右手の(0,0)から7,8,9...と割り当てられます。これらの割当をそのまま物理的な配置順に並べ、行の区切りに0を付けます。

```
"layout":[
    4, 5,        11,10, 0,
    1, 2, 3,   9, 8, 7
]
```



### オートスリープ

電池駆動時に一定時間無入力の状態が続くと自動的にスリープします。

スリープまでの時間は`config.reserve[2]*10min`です。

オートスリープを無効にするには`reserve[2]`に0を指定してください。

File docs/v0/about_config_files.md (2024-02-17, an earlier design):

# 設定について

**このページは旧バージョンのファームウェアについての説明です。最新版ファームウェアの説明は[こちら](../v1/README.md)**

BLE Micro ProではJSON形式の設定ファイルを書き込むことでキーボードごとの設定やキーマップを変更できます。（ファイルシステムの都合で拡張子がJSNになっています。）

- [config.json](edit_config_file.md)
  - キーボードごとのマトリクスの設定や、無線の接続パラメータを設定します。
- [keymap.json](edit_keymap_file.md)
  - キーマップを設定します。
- [tap_term.json](edit_other_config_file.md#tapping_term.jsonの設定)
  - キーコードごとのタッピングタームを設定します。
- [encoder.json](edit_other_config_file.md#encoder.jsonの設定)
  - ロータリーエンコーダの動作を設定します。

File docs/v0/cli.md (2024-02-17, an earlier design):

# CLI

**このページは旧バージョンのファームウェアについての説明です。最新版ファームウェアの説明は[こちら](../v1/README.md)**

BLE Micro Proに各種のコマンドを命令したり、デバッグメッセージを確認したりできます。

BLE Micro ProのCLIを開くには、[QMK Configurator](https://sekigon-gonnoc.github.io/qmk_configurator)か、TeraTermやscreen, cuなどからシリアルポートを開いてください。

| command | description |
| --- | --- |
| reset | Reset system |
| adv | Start advertising |
| dfu | Jump to bootloader |
| show | Show bonded devices |
| del | Delete bond information |
| help | Show this message |
| map | Show keymap |
| conf | Show config |
| conv | Show keymap |
| update  | Update file |
| remove  | Remove file (0: config.json, 1:keymap.json) |
| dump | Dump memory |
| dumps | Dump memory |
| led | LED control |
| ee | eeprom control (show, save, del) |
| web | Start web config mode |
| i2c | Test i2c |

## adv `<id>`

 id番目のペアリング済みデバイスに向けてアドバタイズを開始します。分割マスター設定の場合、スレーブデバイスのスキャンも開始します。idを指定しない場合はペアリングしていないデバイスも含めすべてのデバイスに向けてアドバタイズを開始します。  
 ペアリング済みデバイス一覧はshowコマンドで確認できます

## show

BLEのペアリング状況(ID, role, MAC)を表示します。

## del `<id>`

id番のデバイスとのペアリングを削除します。別途相手デバイス側に残っているペアリング情報も削除してください  
idを指定しない場合すべてのペアリング情報を削除します

## conv `<string>`

`<string>`をキーコードに変換します。keymap.jsonに使える文字列かどうか確認できます。

## remove `<id>`

マスストレージ上のファイルを削除しデフォルトのファイルを復元します。  
0: config.json, 1: keymap.json, 2:tapping_term.json

## led `<pattern>`

LEDを点灯します

## ee [show, save, or del]

eepromをエミュレーションします。eeprom上に今の設定を保存したい場合はsaveしてください。

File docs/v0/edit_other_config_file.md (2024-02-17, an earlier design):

# その他の設定ファイルを編集する

**このページは旧バージョンのファームウェアについての説明です。最新版ファームウェアの説明は[こちら](../v1/README.md)**

## macro.txtの設定(application 0.10.2以降)

- マクロの内容を編集できます。マクロ機能の詳細についてはQMKのドキュメントを参照してください。
- VIAのMacroタブを使って設定することもできます。設定方法についてはVIAのドキュメントを参照してください。
- 1行目は必ず`macro`にする必要があります。
- 2行目から順に1行ずつ`MACRO00`, `MACRO01`, ... `MACRO15`を押したときのマクロになります。マクロに改行(ENTER)を含めたい場合は`\n`を使ってください。
- 0~15まで合計で1024バイト分のマクロを保存できます。
- アスキー文字で割り当てられないマクロは下記エスケープシーケンスで表現します。

  | エスケープシーケンス | 役割          |
  | -------------------- | ------------- |
  | `\n`                 | KC_ENT        |
  | `\t`                 | KC_TAB        |
  | `\b`                 | KC_BSPACE     |
  | `\\`                 | KC_BSLASH     |
  | `\d`                 | KC_DEL        |
  | `\e`                 | KC_ESC        |
  | `\T(KC_YY)`          | SS_TAP(X_YY)  |
  | `\D(KC_YY)`          | SS_DOWN(X_YY) |
  | `\U(KC_YY)`          | SS_UP(X_YY)   |

- `\T`, `\D`, `\U`に続くキーコードの表記法はkeymap.jsonと同様です。
- SS_DELAYに当たる機能は実装されていません。

### 設定例

```txt
macro
Macro\nTest
\D(KC_LGUI)\T(KC_L)\U(KC_LGUI)
```

- 上記内容でmacro.txtを保存後、キーマップに下記のいずれかの方法でMACROxxを割り当てることでマクロが呼び出せるようになります。
  - keymap.jsonを直接編集する
  - QMK Configuratorで`ANY(MACROxx)`を指定する
  - VIAでMxxを設定する
  - Remapで0x5f12~を設定する
- MACRO00: 下記文字列を入力

  ```
  Macro
  Test
  ```

- MACRO01: (Windowsの場合)画面ロック
  - `\T`を使わずに`\D(KC_LGUI)l\U(KC_LGUI)`としても同じ動作です。

## tapping_term.jsonの設定

- get_tapping_term()で返すキーコードとタッピングタームのペアを設定します。
- KC_NOに設定したタッピングタームがデフォルト値になります。
- KC_NOは一番最後に設定してください。

  ```
  {"tapping_term":{
        "LT(1,KC_A)":300,  
        "KC_NO":200,
        }}
  ```

## encoder.jsonの設定

- 最大4つのエンコーダを接続できます。（分割型の場合Master側のみ）

- enabledを1にすることでエンコーダ機能が有効になります。なお、この機能を使用する場合は電流消費量が平均で100uAくらい増加します。

| メンバ | 役割 |
| --- | --- |
| pin | エンコーダのA相、B相を接続したピンを指定します |
| step | エンコーダが何ステップ移動したらアクションを実行するか指定します |
| action | レイヤごとにCW,CCW回転したときのアクションをキーコードで指定します。5レイヤまでアクションを指定できます。6レイヤ以上に移動した場合にはデフォルトレイヤのアクションが実行されます。アプリケーションv0.11.2からは設定の仕方によってキーマップ上のキーコードを参照するように指定できます(後述)。これにより、VIA/Remapからアクションを設定できるようになります。 |

アクションは基本的には指定したキーコードをタップするのと同等の動作ですが、モディファイアのみ若干異なる動作をします。

モディファイア付きのアクションを実行した場合、

- 約500ms間エンコーダの操作をしない
- 他のエンコーダのアクションを実行する
- キー入力が発生する

のいずれかまで、モディファイアが保持されます。

これにより、例えば`Alt+Tab`でウィンドウを切り替えるときにウィンドウ一覧がしばらく表示できるなど、モディファイアを押した状態で他のキーを連打するような動作が便利になります。

もしこの機能を無効にしたい場合、[ファームウェアを自分でビルド](build_firmware.md)して `bmp_encoder_reaed`関数を上書きしてください。

### (アプリケーションv0.11.2以降)アクションを直接指定する代わりにキーマップ上のキーコードを参照する

- 各エンコーダ設定の"action"の1つ目を["KC_TRNS", "KC_NO"]に設定する
- 各エンコーダ設定の"action"の2つ目を参照したいキーマップの連番（CONFIG.JSNのlayoutで指定している番号）に設定する。たとえばCW方向では13, CCWでは14を参照したいときは["ANY(13)", "ANY(14)"]とする
- 該当するキーマップへ回転時に実行したいキーコードを設定する

例：owl8の場合は下記のように設定すると、キーマップの最上段をREMAPから書き換えることでエンコーダの動作を設定できます

- config.json
 
```json
{"config":{"version":2,
"device_info":{"vid":"0x5946","pid":"0x0008","name":"owl8","manufacture":"yfuku","description":""},
"matrix":{"rows":1,"cols":16,"device_rows":1,"device_cols":16,"debounce":1,"is_left_hand":1,"diode_direction":0,"row_pins":[],"col_pins":[20,17,15,13,19,18,16,14,7,8,9,10],
"layout":[
 13, 14, 15, 16,  0,
  9, 10, 11, 12,  0,
  1,  2,  3,  4,  0,
  5,  6,  7,  8]},
"mode":"SINGLE","startup":1,
"peripheral":{"max_interval":30,"min_interval":30,"slave_latency":16},
"central":{"max_interval":30,"min_interval":30,"slave_latency":0},
"led":{"pin":255,"num":0},
"keymap":{"locale":"US","use_ascii":0},
"reserved":[0,0,0,0,0,0,0,0]}}
```

- encoder.json

```json
{"encoder":
{"enabled":1,
"definition":[
{"pin":[7,8],"step":4,"action":[["ANY(1)","ANY(0)"], ["ANY(13)","ANY(14)"], ["ANY(0)","ANY(0)"], ["ANY(0)","ANY(0)"], ["ANY(0)","ANY(0)"]]},
{"pin":[9,10],"step":4,"action":[["ANY(1)","ANY(0)"], ["ANY(15)","ANY(16)"], ["ANY(0)","ANY(0)"], ["ANY(0)","ANY(0)"], ["ANY(0)","ANY(0)"]]}
]}}
```

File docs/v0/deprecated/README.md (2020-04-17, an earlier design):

# 古い情報

nrf52ブランチを使っていたころの古い情報です。

## 使い方(ソフトウェア)

nrf52対応のqmk_firmwareは[こちら](https://github.com/sekigon-gonnoc/qmk_firmware/tree/nrf52)

- 既にqmk_firmwareを使っていて別のブランチとして用意したい場合
```
    git remote add sekigon https://github.com/sekigon-gonnoc/qmk_firmware.git
    git fetch sekigon
    git checkout -b nrf52 sekigon/nrf52
```

- 既にqmk_firmwareを使っていて別のフォルダに置きたい場合

 ```
    git clone  -b nrf52 https://github.com/sekigon-gonnoc/qmk_firmware.git ble_micro_pro
 ```

- 初めて使う場合

```
    git clone --depth 1 -b nrf52 https://github.com/sekigon-gonnoc/qmk_firmware.git
```

### ビルド環境
pro micro用の環境に加えて、arm-none-eabi-gccが必要です。(Version 7-2017-q4-majorで動作確認)
QMK公式のセットアップ手順の際に全てをインストールしていれば、arm用の環境も同時にインストールされているはずです。
arm用の環境を外してセットアップしていた場合は、もう一度セットアップ用のコマンドを実行すれば追加インストールできます。

また、[nRF5_SDK v15.0.0](https://developer.nordicsemi.com/nRF5_SDK/nRF5_SDK_v15.x.x/)をダウンロードして適当な場所に展開してください。

### ファームウェア作成

#### オプション設定

* Macの場合、rules.mkのMOUSEKEY_ENABLEをyesにしておかないと認識されないようです
* config.hに`ENABLE_STARTUP_ADV_NOLIST`を指定すると起動時に自動でアドバタイズが始まります

#### キーマップ
サンプルを参考にして(分割型の場合マスタ側のキーに)以下の関数を実行するカスタムコードを設定することをお勧めします。

|関数|説明|
|:--|:--|
|advertising_wo_whitelist()|新しいデバイスとペアリングするときに使います。
|restart_advertising_id(id)|指定したidのデバイスとの接続を試みます。分割型の場合id=0はスレーブとなるため、id=1から各デバイスに割り当てられます。
|set_usb_enabled(bool)|USB経由の送信を有効/無効にします。起動時は無効になっているので、matrix_init_user中で有効にするか、キーマップに割り当ててください。
|set_ble_enabled(bool)|BLE経由の送信を有効/無効にします。起動時は有効になっています。

### ファームウェアの書き込み
SWDでの書き込みと、ブートローダ書き込み済みの場合はDFUでの書き込みに対応しています。
以下ではDFUでの書き込みについて説明します。

#### セットアップ(Windows(MSYS2))
[nrfutil.exe](https://github.com/NordicSemiconductor/pc-nrfutil/releases)をダウンロードし、~/qmk_utilに保存します。

#### セットアップ(Mac, Linux)
pipでnrfutilを入れます。(python2.7)
    
    pip install nrfutil

#### パッケージの作成と書き込み

ビルドする前に環境変数としてnRF SDKの場所を設定してください

    export NRFSDK15_ROOT=<path to sdk> #例 /c/dev/nRF5_SDK_15.0.0_a53641a
    
初回はライブラリをビルドするため時間がかかります。分割型の場合はmaster用とslave用の両方をビルドしてください。

    make <keyboard>/<master or slave>:nrfutil
を実行することで、ビルド後にそのままファームウェアが書き込めます。
> Detecting USB port, put your controller into dfu-mode now

と表示されたら、キーボードのリセットボタンを押しながら電源投入、あるいはキーマップに設定したコマンドからブートローダを起動します。初回書き込み時は自動的にブートローダが起動します。
書き込みに成功すれば自動で再起動してUSBキーボードとして認識されます。

[書き込み時にエラーが出る](https://github.com/sekigon-gonnoc/BLE-Micro-Pro/blob/master/FAQ.md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)

##### 書き込み時にusb_serialが見つからないとエラーが出る場合(MacOSなど？)
qmk/tmk_core/nrf.mkの862行目

    $(NRFUTIL) dfu usb_serial -pkg $(TARGET).zip -p $$USB; \
を

    $(NRFUTIL) dfu usb-serial -pkg $(TARGET).zip -p $$USB; \
に書き換えてください

#### (分割型)マスタとスレーブの接続
分割型の場合は、初回起動時にマスタとスレーブの接続が確立してからパソコン等とのペアリングを実行してください。
そのため、初回起動時はUSB接続し、TeraTermなどのターミナルソフトを使ってシリアルポートを開いて、情報を確認しながら接続するのが無難です。
マスタのUSB送信を有効にして、スレーブの入力が反映されることを確認してからパソコン等とのペアリングを実行するとよいでしょう。

#### パソコン等とのペアリング
advertising_wo_whitelist()を実行すると、BLE Micro Proがアドバタイズを開始します。パソコン等からスキャンすると、設定したキーボード名のデバイスが確認できるはずです。

2台目以降のパソコン等とペアリングする場合は、他のペアリング済みパソコン等のBluetoothを無効化してからadvertising_wo_whitelist()を実行してください。

指定したペアリング済みパソコン等に接続したい場合、restart_advertising_id(id)を実行します。idはペアリング順です。分割型の場合、id=0はスレーブとなっていることを前提としています。

### 新しいキーボード用ファームウェアの作成
qmk_firmware/keyboard/ble_micro_testが一体型、qmk_firmware/keyboard/ergo42_ble, helix_bleなどが左右分離型のサンプルとなっています。
#### 一体型の場合
編集する必要があるファイルはble_micro_test/config.hとble_micro_test/pro_v1/config.hの2つです。

|パラメータ|変更方法|
|:--|:--|
|MATRIX_ROWS, MATRIX_COLS| 通常通り|
|THIS_DEVICE_ROWS, THIS_DEVICE_COLS| MATRIX_ROWS, MATRIX_COLSと同じ値に設定|
|MATRIX_ROW_PINS, MATRIX_COL_PINS| キーマトリクスに使用しているピン番号を指定|
|IS_LEFT_HAND| 必ずtrue|
|BLE_HID_MAX_INTERVAL| 端末との通信間隔(ms)　下げると消費電力が増える。デフォルトは90|
|BLE_HID_SLAVE_LATENCY| 端末との通信パラメータ　下げると消費電力が増える。HID‗INTERVALに反比例させると良い？　デフォルトは4|

#### 分割型の場合
マスタとスレーブで異なるファームウェアが必要です。現状ではマスタのみUSB接続に対応しています。編集するファイルはergo42_ble/config.hとergo42_ble/master/config.hとergo42_ble/slave/config.hの3つです。

|パラメータ|変更方法|
|:--|:--|
|MATRIX_ROWS, MATRIX_COLS| 通常通り|
|THIS_DEVICE_ROWS, THIS_DEVICE_COLS| マスタ、スレーブそれぞれの列数と行数。8x16まで対応|
|MATRIX_ROW_PINS, MATRIX_COL_PINS| キーマトリクスに使用しているピン番号を指定|
|IS_LEFT_HAND| 左手側ならtrue、右手側ならfalse|
|BLE_NUS_MAX_INTERVAL| 左右間の通信間隔(ms)　下げると消費電力が増える。デフォルトは70|
|BLE_HID_MAX_INTERVAL| 端末との通信間隔(ms)　下げると消費電力が増える。デフォルトは90|
|BLE_HID_SLAVE_LATENCY| 端末との通信パラメータ　下げると消費電力が増える。HID‗INTERVALに反比例させると良い？　デフォルトは4|

## FAQ
### ビルド時にnrf_delay.hが見つからないというエラーが出る。
NRDSDK15_ROOTがあっているか、ダウンロードしたSDKのバージョンが正しいか確認して下さい

### 書き込み時にハッシュエラー(0x0C)が出る
bootloader(v1.0)で使っているライブラリのバグで、正常なバイナリでも書き込みエラーが出ることがあるようです。

* [最新版のbootloader](https://github.com/sekigon-gonnoc/BLE-Micro-Pro/blob/master/ble_micro_pro_bootloader.zip)に書き換える
* master.cかslave.c内の関数をコメントアウトしたり書きかえたりして、バイナリサイズを変える

のいずれかの方法で書き込めるようになります。

bootloaderを書き換えるには以下のコマンドを実行してください。bootloaderの書き換えに失敗すると文鎮化する恐れがあるため絶対に途中でケーブルを抜かないでください。

`nrfutil dfu usb_serial -pkg ble_micro_pro_bootloader.zip -p <ポート名>`

### 書き込み時にusb_serialが見つからないとエラーが出る
qmk/tmk_core/nrf.mkの862行目

`$(NRFUTIL) dfu usb_serial -pkg $(TARGET).zip -p $$USB; \`

を

`$(NRFUTIL) dfu usb-serial -pkg $(TARGET).zip -p $$USB; \`

に書き換えてください

### PCやmaster-slaveの接続が上手くいかなくなった
両方のデバイス(PCとmaster, masterとslave)からペアリング情報を消してから再ペアリングしてください。

後述のターミナルを使って確認しながら削除・再ペアリングするとわかりやすいです。

### ペアリングが上手くいったのか、情報を消せたのかわからない
Tera Terminal等のターミナルソフトでファーム書き込み済みBLE Micro Proのターミナルを開くと、ペアリングの確認や削除ができます。

また、BLE接続時・切断時にメッセージが表示されます。

|コマンド |説明  |
|-|-|
|help|コマンド一覧を表示|
|adv|デバイスの探索を開始|
|show|保存済みのペアリングの数を表示|
|del [id]|id番目のペアリングを削除|

### チャタリングする
config.hのDEBOUNCEを1ずつ増やしてみてください。

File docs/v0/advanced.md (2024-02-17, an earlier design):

# 発展編

**このページは旧バージョンのファームウェアについての説明です。最新版ファームウェアの説明は[こちら](../v1/README.md)**

ファームウェアに機能を追加するために自分でビルドする方法や、トラブル時に役立つ情報をまとめます。

- [ファームウェアをビルドする](build_firmware.md)
- [CLIから操作する](cli.md)
- [セーフモードについて](safemode.md)

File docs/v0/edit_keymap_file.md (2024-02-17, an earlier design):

# キーマップの設定

**このページは旧バージョンのファームウェアについての説明です。最新版ファームウェアの説明は[こちら](../v1/README.md)**

## KEYMAP.JSNの編集
- 489キー分の設定を保存できます

- [QMK Configurator](https://sekigon-gonnoc.github.io/qmk_configurator/)で生成したkeymap.jsonをそのまま読み込めます。

- keymap.json, tapping_term.jsonは即時反映されるので再起動は必要ありません。

- 認識できる KC_XX はQMK Configurator準拠です。
    `"KC_EXLM", "KC_AT", "KC_HASH"`

- 書き込み時にはKC_を付けなくても認識されます。読み出し時には自動でKC_が付きます。
    `"KC_A", "A", "a"` 

- !, @, # などの記号をそのまま書き込むこともできます。`\`, `"` を設定するときはエスケープしてください。  
    `"!", "@", "#", "\\", "\""`

- JPキーボードとして使いたい場合は、config.jsonのlocaleをJPに設定した上で、[QMK Configurator](https://sekigon-gonnoc.github.io/qmk_configurator/)のJPタブからキーコードを選択してください

- カスタムキーコードとして[BLE Micro Pro固有のキーコード](#ble-micro-pro固有のキーコード)にも対応しています。

- 自分でファームウェアをビルドしてカスタムキーコードを設定した場合でも辞書を定義しておけば認識できます。ANY(1255)などして数値で直接指定する方法もあります。

## BLE Micro Pro固有のキーコード

BLE Micro Pro用のQMKには、QMKのカスタムキーコードとして定義済みの機能と、レイヤなどの引数をとる独自の構文が用意されています。

### カスタムキーコード

| keycode | 内容 |
| --- | --- |
| BLE_DIS | Disable BLE HID sending |
| BLE_EN  | Enable BLE HID sending |
| USB_DIS | Disable USB HID sending |
| USB_EN  | Enable USB HID sending |
| SEL_BLE | Enable BLE and disable USB |
| SEL_USB | Enable USB and disable BLE |
| ADV_ID0 | Start advertising to PeerID 0 |
| ADV_ID1 | Start advertising to PeerID 1 |
| ADV_ID2 | Start advertising to PeerID 2 |
| ADV_ID3 | Start advertising to PeerID 3 |
| ADV_ID4 | Start advertising to PeerID 4 |
| ADV_ID5 | Start advertising to PeerID 5 |
| ADV_ID6 | Start advertising to PeerID 6 |
| ADV_ID7 | Start advertising to PeerID 7 |
| AD_WO_L | Start advertising without whitelist  |
| DEL_ID0 | Delete bonding of PeerID 0 |
| DEL_ID1 | Delete bonding of PeerID 1 |
| DEL_ID2 | Delete bonding of PeerID 2 |
| DEL_ID3 | Delete bonding of PeerID 3 |
| DEL_ID4 | Delete bonding of PeerID 4 |
| DEL_ID5 | Delete bonding of PeerID 5 |
| DEL_ID6 | Delete bonding of PeerID 6 |
| DEL_ID7 | Delete bonding of PeerID 7 |
| DELBNDS | Delete all bonding |
| ENT_DFU | Start bootloader |
| ENT_WEB | Start web configurator |
| ENT_SLP | Deep sleep mode |
| BATT_LV | Display battery level in milli volts |
| SAVE_EE | Save eeprom config |
| DEL_EE  | Delete eeprom config |
| xEISU | Send `LANG1` or `` Alt + ` `` |
| xKANA | Send `LANG2` or `` Alt + ` `` |

### 拡張キーコード

- LTやTDを使いやすくした独自の構文です。
- `EX()`で囲う必要があります。例: `EX(LTE(2, xEISU))`
- 全ての関数でKCに16ビットコードが使えるので、モディファイアと組み合わせたキーやカスタムキーコードを指定できます。
- KEYMAP.JSNの中に32種類まで登録でき、これを超えた場合は無視されます。

| 構文 | 内容 |
| --- | --- |
| LTE(layer, kc) | LTと同じ。`EX(LTE(2, xEISU))` |
| TLT(layer1, layer2, layer3, kc) | LTとtri_layer_updateを組み合わせたもの |
| TDD(kc1, kc2) | 一回タップするとkc1, 二回タップするとkc2が入力される |
| TDH(kc1, kc2) | タップするとkc1, ホールドするとkc2が入力される |
| CMB(kc1, kc2, kc3) | コンボの設定。このキー自体を押しても何も起きない。kc1とkc2を同時押しすることでkc3が入力される。kc2には8bitコードしか指定できない |

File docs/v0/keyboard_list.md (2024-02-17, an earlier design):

# 無線化の実績のあるキーボード一覧

**このページは旧バージョンのファームウェアについての説明です。最新版ファームウェアの説明は[こちら](../v1/README.md)**

- 無線化の報告のあるキーボードの一覧です。このリストに無いからといって対応していないとは限りません。また、無線化できることを保証するものではありません。

- LPME-IOを使うにはキーボードの左右の有線通信がI2Cである必要があります。とくにOLEDに対応しているキーボード等の場合は、I2C用のピンをTRRSジャックに接続する改造を施すことでI2C化できる場合があります。

|keyboard|Web Configurator|LPME-IO|電源|
|--|--|--|--|
|7skb (Pro)|✔|✔|オプション基板|
|Angle64|✔||オプション基板|
|Bat43|✔||電池ホルダ内蔵|
|Blockey|||電池基板|
|Bootleg31|||電池ボックス内蔵|
|Choco60|✔|?|電池基板|
|Claw44|✔|?|電池基板|
|Cocoa40|✔|?|電池基板|
|Corne Cherry (Light), Chocolate|✔|✔*|電池基板|
|cscs64|||電池ボックス内蔵|
|Dozen0|✔||電池基板|
|Ergo42|✔|✔|電池基板|
|ErgoDash (mini)|✔|✔*|電池基板|
|Helix|✔|✔*|電池基板|
|Iris rev?||?|電池基板|
|Kugel-1|✔||電池ボックス内蔵|
|Let's Split|✔|?|電池基板|
|Lily58 (Lite)|✔|✔*|電池基板|
|Lunakey Mini|✔|?|電池基板|
|Meishi|✔||電池基板|
|Mint60|✔|✔*|電池基板|
|Naked48LED|✔||電池基板|
|Naked60BMP|✔||オプション基板|
|Naked64SF|✔||電池ホルダ内蔵、単4オプション基板あり|
|Nomu30|✔||電池基板|
|Numatreus|✔||電池基板|
|Otaku Split|✔|?|オプション基板|
|Rect44|||電池ボックス搭載|
|Runner3680|✔|?|電池基板|
|Treadstone48|✔||電池基板|
|uzu42|✔|?|電池基板|
|Zinc|✔|?|オプション基板あり|

*LPME-IOを使うには改造が必要

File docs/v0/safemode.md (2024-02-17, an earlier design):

# セーフモードについて

**このページは旧バージョンのファームウェアについての説明です。最新版ファームウェアの説明は[こちら](../v1/README.md)**

CONFIG.JSNの中身が間違っている場合などにBLE Micro Proがセーフモードとして起動することがあります。発生要因は以下のとおりです。

- CONFIG.JSNの中身が間違っている
- row0, col0のスイッチが押された状態で起動した
- `BMP_FORCE_SAFE_MODE`フラグを有効にしたファームウェアを書き込んだ
- BLE Micro Pro内部でエラーが一定回数以上発生した

セーフモードで起動すると書き込んだCONFIG.JSNの代わりにファームウェアに埋め込まれたデフォルトの設定が使用されます。

セーフモードで起動しているかどうかは[CLI](cli.md)に繋いだときの表示名がキーボード名か、safemodeになっているかで判別できます。

セーフモードから復帰するには一度リセットまたは電源再投入してください。

何度リセットしてもセーフモードになる場合、CONFIG.JSNの中身が間違っている可能性があるため、中身を確認して書き換えてください。

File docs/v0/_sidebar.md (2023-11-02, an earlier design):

* [はじめに](/)
  * [特徴/機能一覧](features.md)
  * [対応キーボード一覧](keyboard_list.md)
  * [自作キーボードキットを無線化する](getting_started.md)
  * [無線対応の自作キーボードを設計する](design_guide.md)

* [設定について](about_config_files.md)
  * [キーボードの設定ファイルを編集する](edit_config_file.md)
  * [キーマップの設定ファイルを編集する](edit_keymap_file.md)
  * [その他の設定ファイルを編集する](edit_other_config_file.md)

* [発展編](advanced.md)
  * [ファームウェアをビルドする](build_firmware.md)
  * [CLIから操作する](cli.md)
  * [セーフモードについて](safemode.md)

* [試験的機能](experimental.md)

* その他
  * [BLE-USB HIDブリッジドングル](bridge_dongle.md)

* [FAQ](FAQ.md)
* [古い情報](deprecated/README.md)

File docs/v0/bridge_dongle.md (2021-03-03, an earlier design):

# BLE-USB HIDブリッジドングル

(開発中)BLE Micro ProやMDBT50Q-RXを使って、BLEとUSBのHIDをブリッジします。
```
PC <--USB HID--> Dongle <--BLE HID--> Keyboard
```

- パソコンからはドングルがUSBキーボードに見えるため、OSのBLEサポートに依存せずにキーボードを無線接続できます
- BLE Micro Pro用のファームウェアを使ったキーボード意外と接続しても正しく動作しません
  - 2020/05現在、レポートディスクリプタの解釈を飛ばして固定値を使用しているため
- 旧ファームウェアのプロジェクト構造を使用しているため、[nRF SDKを用意してビルドする](deprecated/README.md)必要があります
  ```
    git checkout nrf52
    make ble_micro_pro/(dongle|mdbt50rx):(nrfutil|uf2)
  ```
- 最大5台同時に接続出来ます

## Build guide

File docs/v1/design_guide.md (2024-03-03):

# 無線対応の自作キーボードを設計する

## ハードウェア概要

connection

[ハードウェア仕様](features.md#ハードウェア仕様)

### 使用上の注意点

Pro Microとの互換性を意識して設計されていますが、以下の点にご注意ください。

- 入出力は3.3Vです。ただし、5・6番ピン(SDA・SCL)のみFETによるレベルシフト回路を実装しています。
  - **5・6番ピン以外は5Vトレラントではありません**
  - 5・6番ピンはNeoPixel系のLEDの駆動には使えません

- RAWピンの最大電圧は5Vです。

- コンスルーに対応しているため、はんだ付けせずに基板に取り付けられます。

## 電源

- USBコネクタの横にあるBATピン、あるいはUSBコネクタ、RAWピン、VCCピンから電源供給できます。
  - BATピン (1.7V--3.6V)
  - RAW or VCC (3V--5V)
    - ただし、RAW, VCC >= BATのときのみ

- バッテリー駆動する場合は1.7Vから3.6Vの電源が必要です。したがってLiPoバッテリーを使用する場合は別途レギュレータをつけて電圧を下げてください。

- 特に分割型のキーボードをコイン電池で駆動する場合は、許容電流量を確保するため、電池を並列接続することをおすすめします。
このとき、ショットキーバリアダイオードを間に入れるのを忘れないでください。

  <details>
  <summary>解説</summary>
    分割型の場合、BLE Micro Proの平均電流量は300uAくらいになる場合があります。コイン電池の定格連続電流は200uAくらいのため、電池を並列にして定格以下に抑えられるようにします。このとき、並列に繋いだ電池に電位差があると電池間で電流が流れてしまうため、ダイオードを挟んで防止します。ダイオードにはショットキーバリアダイオードという電圧降下が小さいダイオードを使うことで、電池の電圧が下がってきてもギリギリまで使い切ることができます。
  </details>

- コイン電池で駆動する場合には前述のダイオードのあとに100uFくらいの積層セラミックコンデンサを入れてください。

  <details>
  <summary>解説</summary>
  BLE Micro Proが無線通信するとき、瞬間的に6mAくらいの電流を必要とします。コイン電池は内部抵抗が大きいのでこの電流で電圧が瞬間的に下がってしまい、必要な電圧を下回ってBLE Micro Proがリセットしてしまう可能性があります。コンデンサを入れることでこのピークを鈍らせてリセットを防止します。
  </details>

コイン電池をつかった電池基板の例は[こちら](https://github.com/sekigon-gonnoc/BLE-Micro-Pro/tree/master/CoinCellHolder)

## 配線

- 回路図上の配線はPro Microとほぼ同じです。

  - PIN13を使わないようにすると、12ピンのコンスルーだけで必要なピンをすべて基板に接続できます。

    connection

     赤枠の部分で基板と接続すると、左上のGNDは他のピンで接続されているため、右下のPIN13以外はすべて接続された状態になります。

  - RAWと4V3は繋がないで、NeoPixelなどのLEDの電源には4V3を使ってください。

  - LPME-IOに対応させる場合は左右の有線通信にI2Cを使えるようにしてください。外部プルアップはしないでください。
    - VCC, GND, I2C対応ピン(5, 6番ピン)をTRRSジャックに配線してください
      - SDA/SCLの割当はファームウェアで変更可能ですが、デフォルトではPro Micro同様に5番がSDA, 6番がSCLです
      - Pro Micro, TRSケーブルを使用した場合にも通信できるようにピン配置に注意が必要です
      - Pro Micro用のファームウェアでは結線に応じて`SOFT_SERIAL_PIN`をD2またはD3にすることで通常のシリアル通信で動作します

## パターン

- 通信の安定性の確保のため、無線用のアンテナ部分を覆う場所は銅箔で埋めないことが一般的に推奨されています。

## LED

### NeoPixel

- NeoPixel系のLEDはUSB電源を供給しているときのみ光らせることができます。
- 5・6番ピンはレベルシフト用回路の影響でNeoPixel系LED駆動には使えません。

### インジケータLED

- ディスクリートLEDをインジケータ用のLEDとして使えます。インジケータLEDでは以下の情報を表示できます。

  - 電池残量：起動時の点滅回数(1~3)で電池残量を表示します。

  - ペアリング中：5秒間隔で点滅を繰り返します。

  - ペアリング完了：長めに1回点滅します。

- LEDと抵抗または定電流ダイオードを直列にBLE Micro Proのピンに接続し、そのピン番号をCONFIG.JSNのreserved[1]に指定してください。

## プルリクエスト

BLE Micro Pro Web Configurator に設定ファイルを登録したい場合は、[設定について](about_config_files.md)を参考にプルリクエストを作成してください。

また、Remapのキーマップ共有機能でデフォルトキーマップを共有しておくとキット購入者が組み立てるときの助けになると思います。

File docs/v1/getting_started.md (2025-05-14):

# 自作キーボードキットを無線化する

- [ハードウェアの準備](#ハードウェアの準備)
  - [BLE Micro Proを取り付ける準備](#ble-micro-proを取り付ける準備)
  - [電源の準備](#電源の準備)
- [BLE Micro Pro Web Configuratorを使ってファームウェアを書き込む](#ble-micro-pro-web-configuratorを使ってファームウェアを書き込む)
  - [キーボードを選ぶ](#キーボードを選ぶ)
  - [ファームウェアのアップデート](#ファームウェアのアップデート)
    - [ファームウェアの書き込みに失敗した場合](#ファームウェアの書き込みに失敗した場合)
  - [設定ファイルの書き込み](#設定ファイルの書き込み)
    - [分割キーボードのマスター側](#分割キーボードのマスター側)
    - [分割キーボードのスレーブ側](#分割キーボードのスレーブ側)
    - [一体型キーボード](#一体型キーボード)
  - [キーマップの書き込み](#キーマップの書き込み)
    - [キーマップ設定の変更](#キーマップ設定の変更)
  - [ペアリングする](#ペアリングする)
    - [(分割型のみ)マスターとスレーブの接続](#分割型のみマスターとスレーブの接続)
    - [パソコン等とのペアリング](#パソコン等とのペアリング)

## ハードウェアの準備

### BLE Micro Proを取り付ける準備

キーボード基板への取り付けにピンヘッダでなくコンスルーを使うことができます。([遊舎工房販売ページ](https://yushakobo.jp/shop/a01mc-00/), [TALP keyboard販売ページ](https://talpkeyboard.stores.jp/items/5e056626d790db16e2889233), [Switch Science 販売ページ](https://www.switch-science.com/catalog/3763/))。 BLE Micro Proはコンスルー対応なので、はんだづけは不要です。

BLE Micro Pro対応を前提に設計されたキーボードキットでは13ピンのコンスルーが必要な場合があります。キーボードキットの必要部品をよく確認してください。それ以外の場合は12ピンのコンスルーを使用するか、13ピンコンスルーをカットしてください。

### 電源の準備

無線運用するにはバッテリーから電源供給する必要があります。

キーボードキットが電池搭載に対応していない場合は、BLE Micro Proに直接電池を接続してください。BLE Micro Pro用に設計された電源基板としては単4電池基板([BOOTH販売ページ](https://nogikes.booth.pm/items/2710739))またはコイン電池基板([遊舎工房販売ページ](https://yushakobo.jp/shop/ble-micro-pro-battery-board/)、[BOOTH販売ページ](https://nogikes.booth.pm/items/1655285))があります。  

## BLE Micro Pro Web Configuratorを使ってファームウェアを書き込む

Google Chromeから[BLE Micro Pro Web Configurator](https://sekigon-gonnoc.github.io/BLE-Micro-Pro-WebConfigurator/)にアクセスするとブラウザからファームウェアのアップデートや各種設定ができます。  

### キーボードを選ぶ

`ナビゲーション付きでセットアップを開始する`ボタンを押すとキーボードの選択画面が表示されます。
リストから無線化したいキーボードを選んでください。

無線化したいキーボードがリストにない場合には、[BMP用の設定を生成する](about_config_files.md)必要があります。また、トラックボール搭載のキーボードなどはデフォルトのファームウェアでは対応できないので、[ファームウェアのビルド](build_firmware.md)が必要です。
設定生成が完了したら、ここでは`ble_micro_pro`または`ble_micro_pro_split`を選択してください。

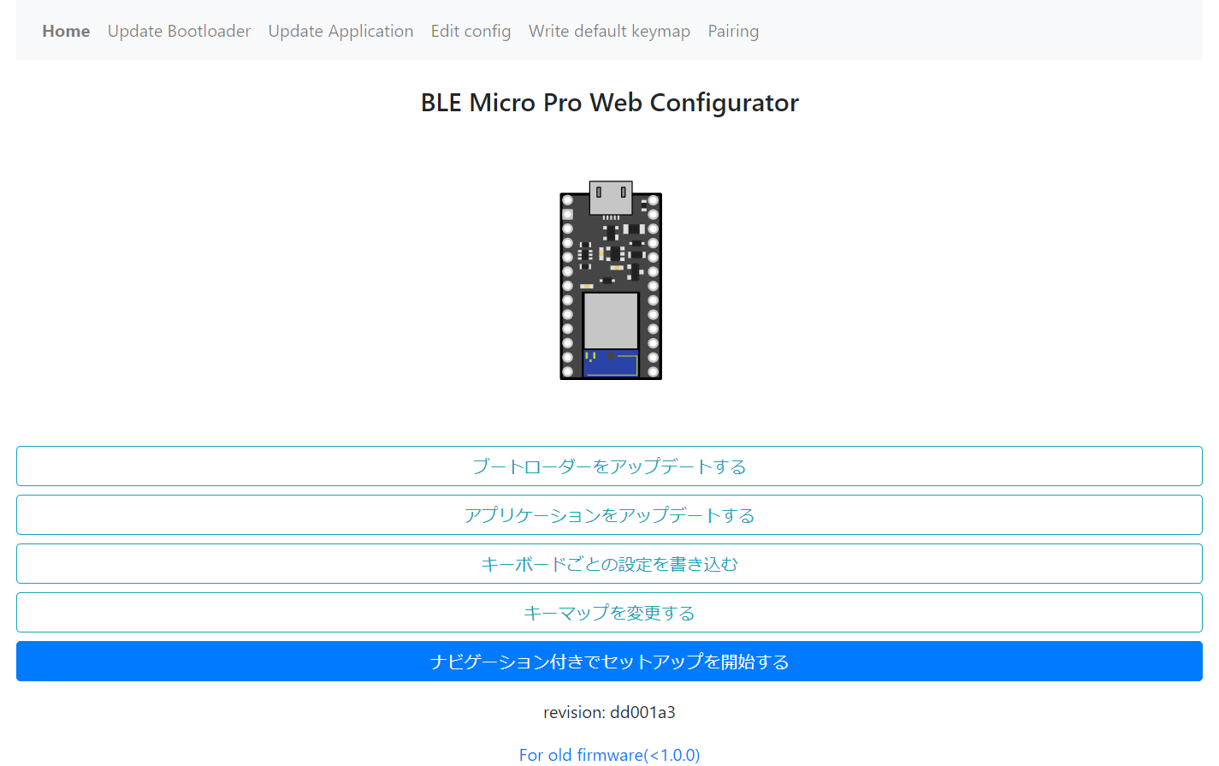
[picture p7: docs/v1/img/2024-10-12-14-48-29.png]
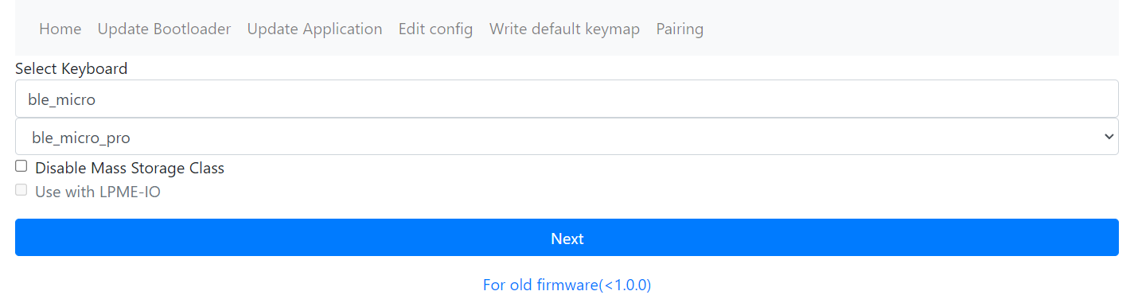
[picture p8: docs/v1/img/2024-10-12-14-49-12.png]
|||
|--|--|
|ホーム画面|キーボード選択画面|

キーボード選択画面では2つのオプションが選択できます。

- Disable Mass Storage Class
  - BLE Micro Proにファームウェアを書き込むとパソコンにUSBケーブルで接続したときに大容量記憶デバイスとして認識されます。セキュリティの都合などで、大容量記憶デバイスとして認識されると困る場合にはこのオプションにチェックを入れることで機能を無効化できます。

- Use with LPME-IO（分割型のみ）
  - 分割型キーボードを無線化するときにBLE Micro Proを2台使った完全無線化をするのではなく、BLE Micro ProとLPME-IOを組み合わせた部分無線化をする場合にはこのオプションにチェックを入れてください。  
  - LPME-IOを使用するにはキーボード側が対応している必要があります。

構成を選択し終わったら`Next`ボタンを押すと次の手順に進みます。

### ファームウェアのアップデート

BLE Micro Proにはブートローダとアプリケーションという2種類のファームウェアを書き込みます。

* リストから最新版のブートローダーを選択してください。
* `Update`をクリックするとUSBデバイスへのアクセスを求めるポップアップが表示されます。
* USBケーブルでBLE Micro ProをPCに接続してください。
   * 分割キーボードの場合はまずマスター側(USB接続でのキー入力に対応させたいほう)をセットアップしてください。
* ポップアップにあたらしく表示されたデバイスを選択して`接続`をクリックすると書き込みが始まります。
  * デバイス名は画像と異なる場合があります。
* 書き込みが成功したら一度USBケーブルを抜き差しし、`Next`をクリックして次のステップに進んでください。
  * 緑色ではなく青や赤の表示が出たら後述の書き込み失敗時の手順を確認してください。
 
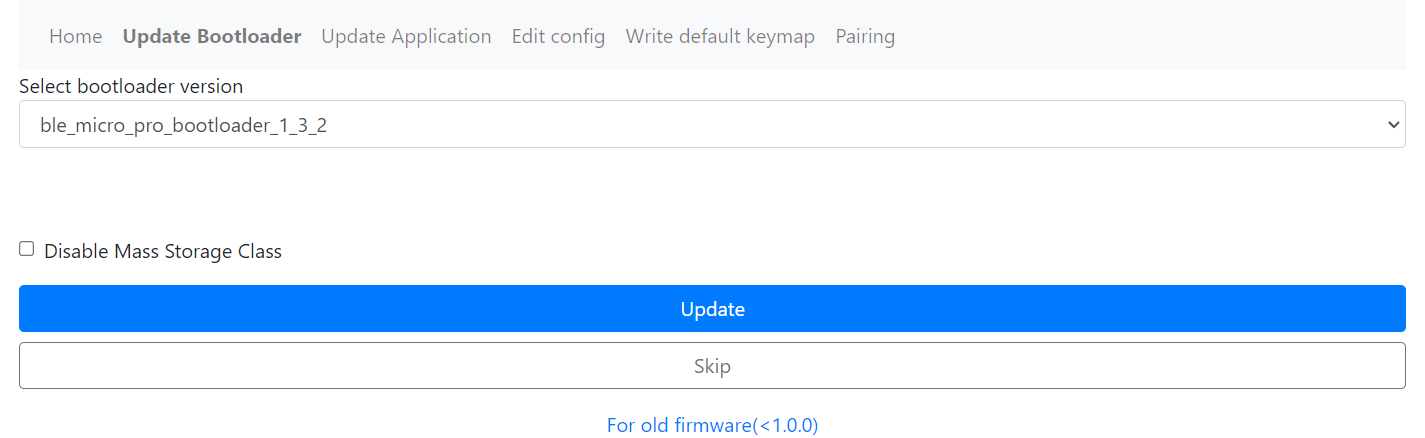
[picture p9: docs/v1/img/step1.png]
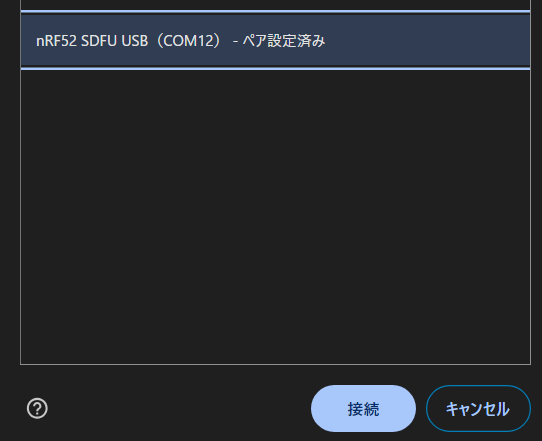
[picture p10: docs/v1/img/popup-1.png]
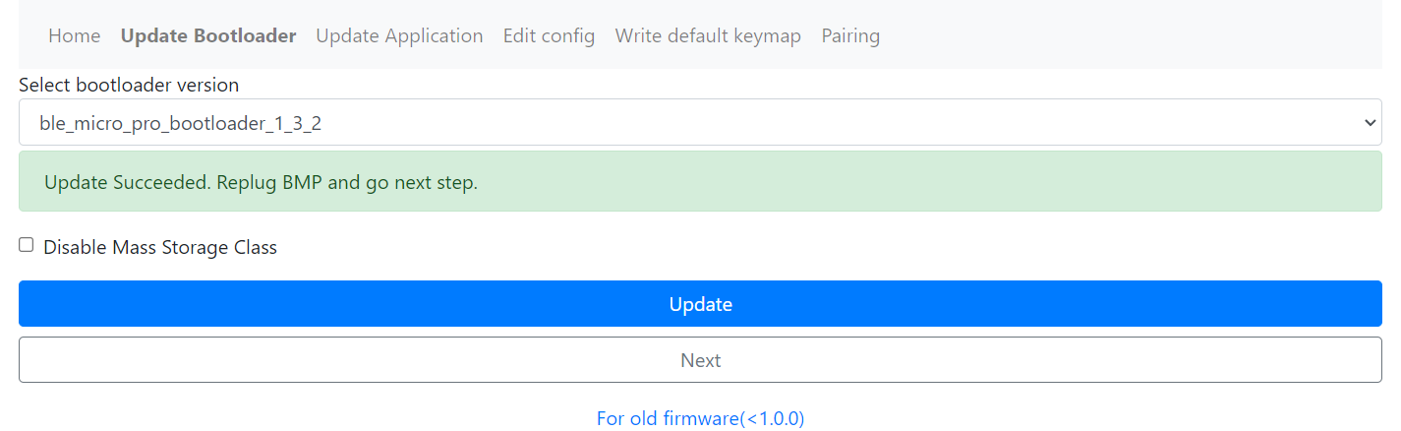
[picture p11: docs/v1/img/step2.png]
|  |  |  |
| --- | --- | --- |

* リストから最新版のファームウェア(`ble_micro_pro_vial_x_y_z`)を選択してください。
* `Update`をクリックするとUSBデバイスへのアクセスを求めるポップアップが表示されます。
* BLE Micro Proを選択して`接続`をクリックすると書き込みが始まります。
  * どのデバイスがBLE Micro Proか分からない場合はUSBケーブルを抜き差ししてデバイス一覧の変化を確認してください。
* 書き込みが成功したら`Next`をクリックして次のステップに進んでください。

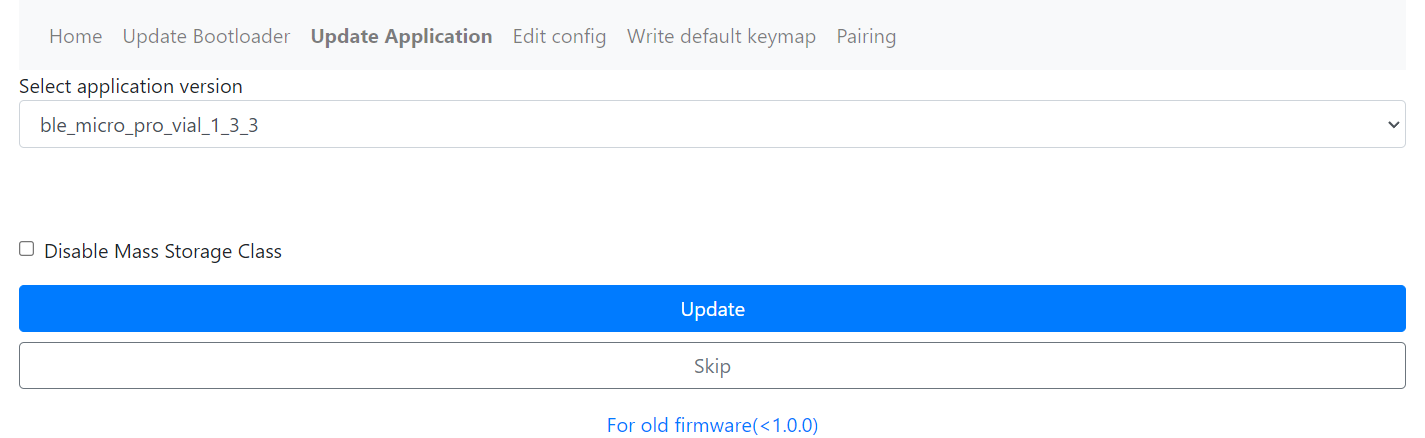
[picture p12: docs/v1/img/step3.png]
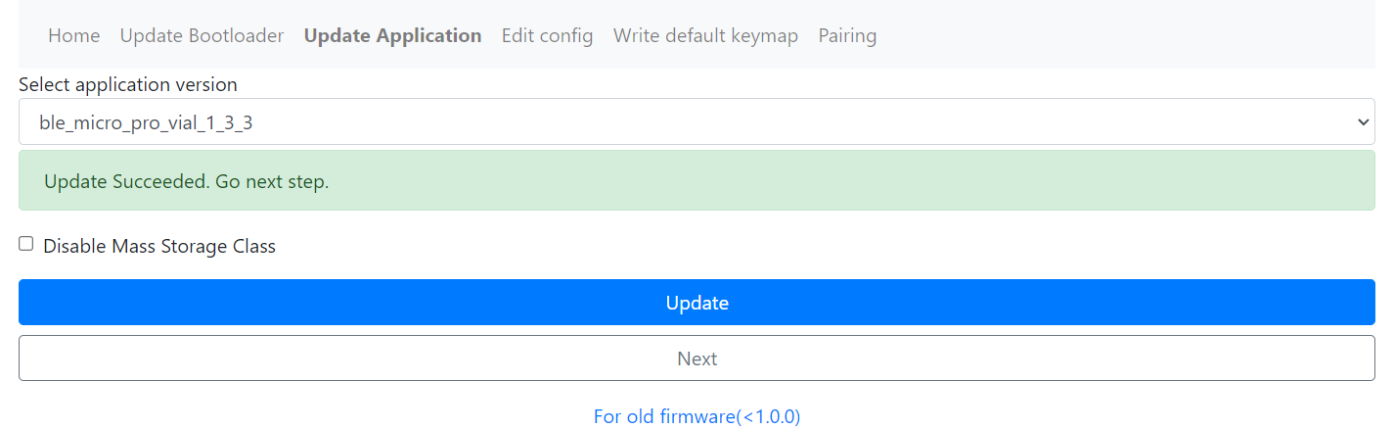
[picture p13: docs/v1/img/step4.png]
|  |  |  |
| --- | --- | --- |

#### ファームウェアの書き込みに失敗した場合

*  "Boot loader is activated. ~"と表示されている場合はそのままもう一度`Update`ボタンをクリックしてください。
*  "Failed to ~"と表示されている場合は他のソフトでシリアルポートを開いていないか確認してください。

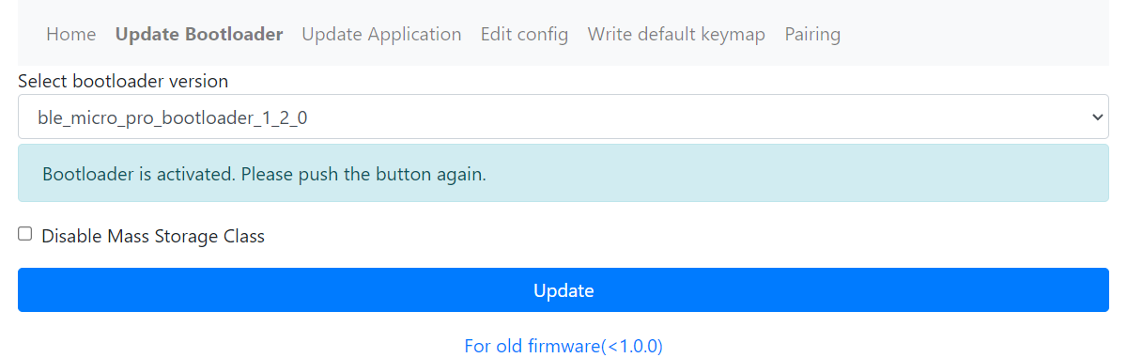
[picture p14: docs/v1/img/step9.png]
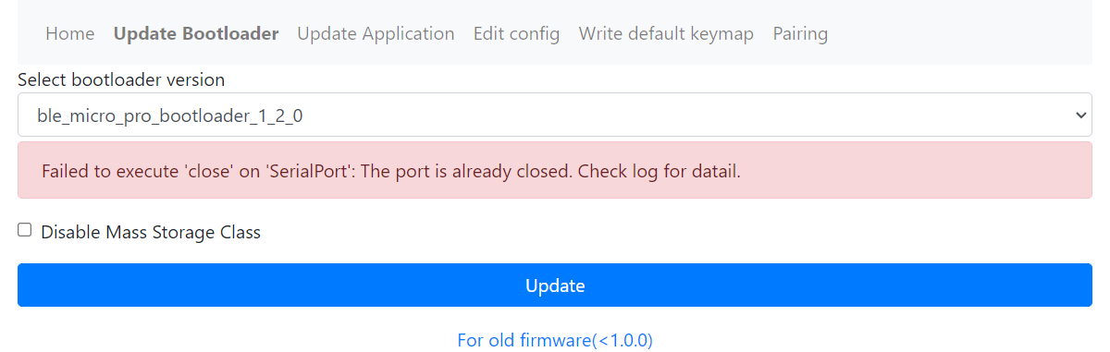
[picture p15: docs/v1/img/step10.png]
|  |  |
| --- | --- |

<details>
<summary>オプションについて</summary>

ファームウェア書き込み時に`Disable Mass Storage Class`のチェックを入れると、
USB接続時にリムーバブルディスクとして認識されなくなります。
</details>

<details>
<summary>
ファームウェアのバージョンについて
</summary>

2つのファームウェアのバージョンは`<major>.<minor>.<revision>`の3つの数字の組み合わせで表されていて、ブートローダとアプリケーションのメジャーバージョンとマイナーバージョンは一致させる必要があります。

特別な事情がない限りは両方ともデフォルトで選択されている最新版を利用してください。なお、メジャーまたはマイナーバージョンが異なるファームウェアへのダウングレード後の動作は保証されません。

</details>

### 設定ファイルの書き込み

設定ファイルの書き込み画面でもキーボードの選択リストが表示されます。
ナビゲーション付きでセットアップを開始した場合は最初に選択したキーボードとレイアウトが選択されているため、ここで選択し直す必要はありません。

自分で生成した設定を書き込みたい場合は、ここで`upload your own`を選択してください。

#### 分割キーボードのマスター側

ナビゲーション付きセットアップで分割キーボードのセットアップを開始した場合は、まずマスター側の設定を書き込みます。

BLE Micro Proを使用した分割キーボードでは、マスター側のみUSB接続でのキーボード動作に対応しています。

* `Is Slave`のチェックが外れていることを確認してください。
* 右側のキーボードをマスターにしたい場合は`Is Left`のチェックも外してください。
* LPME-IOを使用する場合は`Use with LPME-IO`にチェックを付けてください。
* `Update`をクリックするとUSBデバイスへのアクセスを求めるポップアップが表示されます。
* キーボードを選択して`接続`をクリックすると書き込みが始まります。
  * どのデバイスがBLE Micro Proか分からない場合はUSBケーブルを抜き差ししてデバイス一覧の変化を確認してください。
  * ポップアップにキーボードが表示されない場合はファームウェアの書き込みができていないので、最初のステップからリトライしてください。
* 書き込みが成功したら次のステップに進んでください。
  * 数十秒待っても書き込みが完了しなかったらブラウザをリロードしてUSBケーブルを抜き差してからリトライしてください。

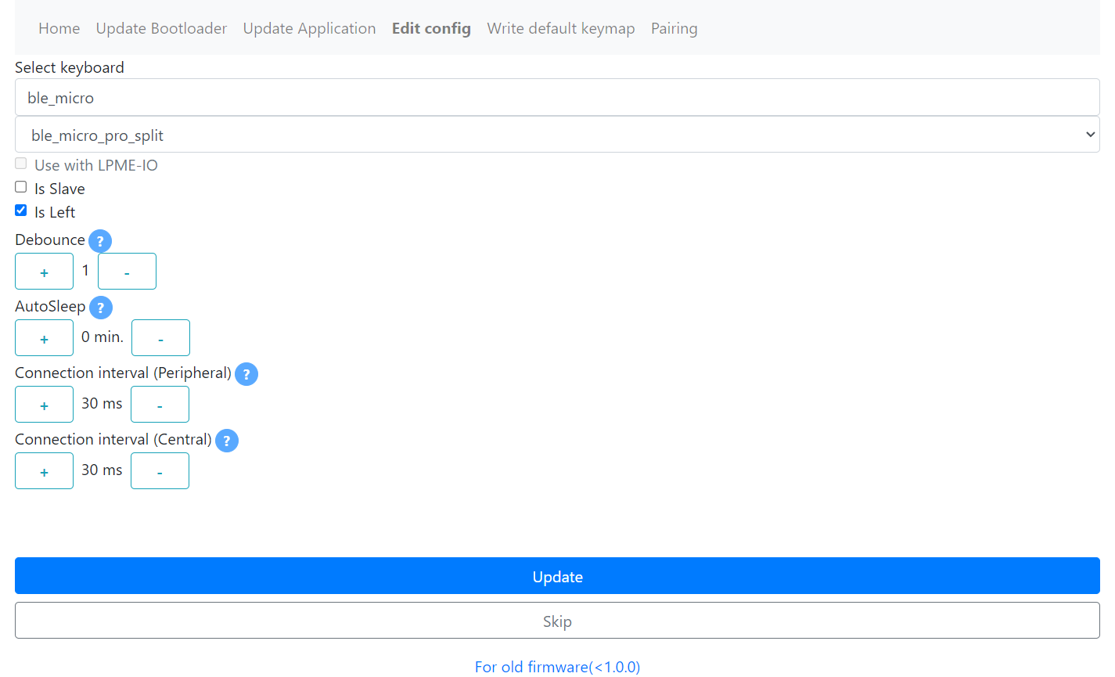
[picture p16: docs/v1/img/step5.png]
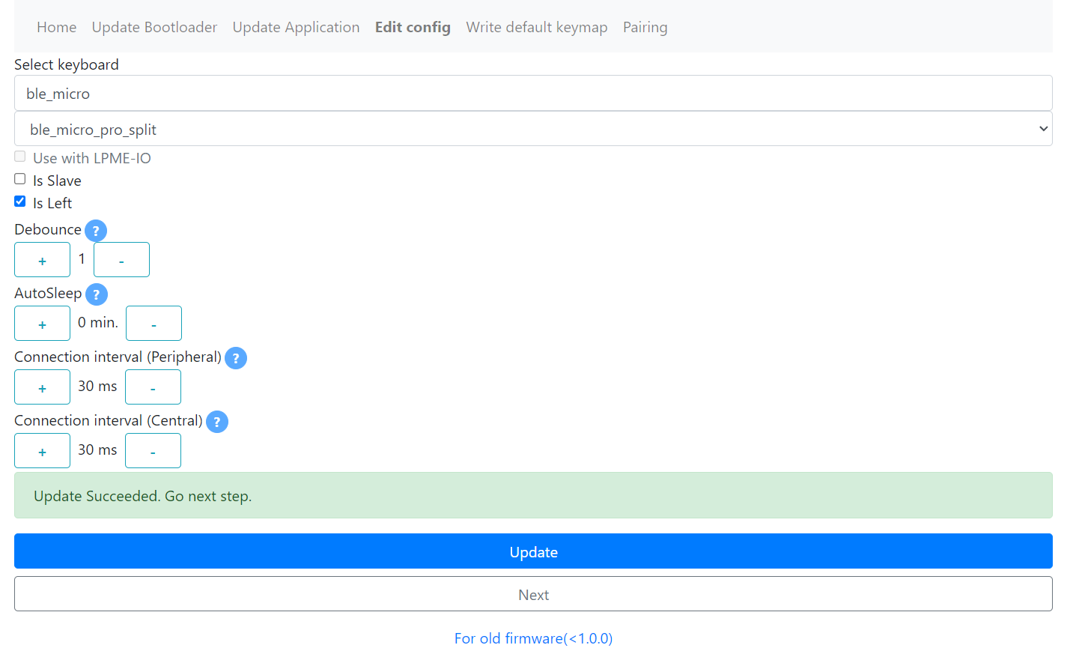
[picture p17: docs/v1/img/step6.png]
|  |  |  |
| --- | --- | --- |

ナビゲーション付きセットアップで分割キーボードのセットアップを開始した場合は、`Next`をクリックして次の画面に進んでください。画面の指示にしたがってBLE Micro Proを差し替えたら、`Next`をクリックすると、スレーブ側のファームウェア書き込み画面に移動します。

|  |
| ------------------  |

#### 分割キーボードのスレーブ側

* `Is Slave`のチェックが付いていることを確認してください。
* `Is Left`のチェックはマスター側と反転させてください。
* `Update`をクリックしてマスター側と同様に設定を書き込んでください。

スレーブ側の設定が完了したらファームウェア・設定の更新は完了です。マスター側をUSB接続し、キーマップの書き込みに進んでください。

#### 一体型キーボード

* `Update`をクリックするとUSBデバイスへのアクセスを求めるポップアップが表示されます。
* キーボードを選択して`接続`をクリックすると書き込みが始まります。
  * どのデバイスがBLE Micro Proか分からない場合はUSBケーブルを抜き差ししてデバイス一覧の変化を確認してください。
  * ポップアップにキーボードが表示されない場合はファームウェアの書き込みができていないので、最初のステップからリトライしてください。
* 書き込みが成功したら次のステップに進んでください。
  * 数十秒待っても書き込みが完了しなかったらブラウザをリロードしてUSBケーブルを抜き差してからリトライしてください。

|  |  |  |
| --- | --- | --- |

<details>

<summary>オプションについて</summary>

- Use With LPME-IO（分割型のみ）
  - 前述の設定と同様です。デフォルトでは最初の画面で選んだ設定が引き継がれています。

- Is Slave（分割型のみ）
  - 分割型の場合、2つのBLE Micro ProにMaster/Slaveという役割が割り振られます。ナビゲーション付きでセットアップを開始した場合は手順に応じて自動的に選択されるため、変更する必要はありません。

- Is Left（分割型のみ）
  - いま設定しているBLE Micro Proを左手に取り付ける場合にはチェックを入れてください。

- Debounce
  - キー入力のチャタリング除去のパラメータです。デフォルトは1で、チャタリングがひどい場合にはチャタリングが無くなるまで1ずつ増やしてみてください。

- Connection interval(Peripheral)
  - 通信間隔の設定です。短くすると入力のラグが減る一方で、電力消費が増加します。
    - 一体型キーボード、または分割型キーボードのMasterを設定している場合はPCとの通信間隔を設定します。
    - 分割型キーボードのSlaveを設定している場合はMasterとの通信間隔を設定します。後述のMaster側の設定と合わせてください。
  
- Connection interval(Central)（分割型Masterのみ）
  - 分割型キーボードのSlaverとの通信間隔を設定します。前述のSlave側の設定と合わせてください。

</details>

### キーマップの書き込み

キーマップの書き込みには[VIA Custom UI for Vial](https://sekigon-gonnoc.github.io/via-custom-ui-for-vial/)を使用します。[Vial](https://vial.rocks/)にも対応しています。また、レイアウトが登録されていれば[Remap](https://remap-keys.app/)からも変更できます。VIA Custom UI for Vialのみ無線経由での書き込みにも対応しています。

<details>

<summary>Vialを使う場合の注意点</summary>

* Vialを利用する場合、ローカル版のVialでは電源投入後の初回の接続には必ず失敗してしまいます。エラーが表示されたらRefreshボタンを押して再読み込みしてください。ブラウザ版では自動でリトライされるため、再読み込みの操作は必要ありません
* 一度Vialと接続した場合、リセットするまでRemapには接続できなくなります。Remapに再接続したい場合は、リセットするか電源を再投入してください
* Remapのマクロ定義とVialのマクロ定義が異なるため、一方で編集したマクロはもう一方で正しく表示されない場合があります。どちらで定義してもマクロの実行は可能です
* USBでの接続のみ対応しています

</details>
</br>

ここではVIA Custom UI for Vialを使った書き換えを説明します。他のサイトを使用する場合は、それぞれの説明を適宜参照してください。

* キーボードのマスター側をUSB接続してください。
* `OPEN`ボタンをクリックして表示されるポップアップから、設定を変更したいキーボードを選択して接続してください。

接続に成功すると画面左側にメニュー一覧が表示されます。`Keymap`, `Quantum`はキーボードによらず表示されるメニューです。`Custom settings`はキーボード固有のメニューです。

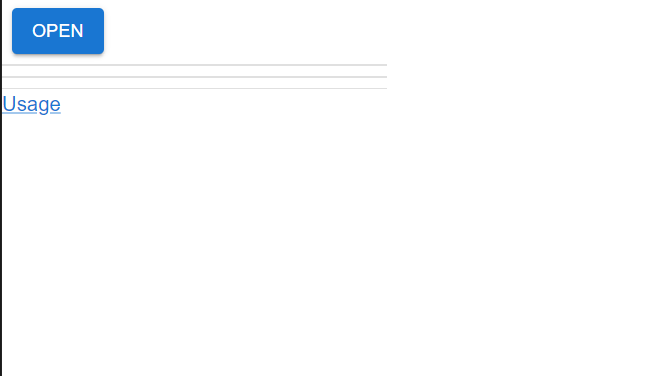
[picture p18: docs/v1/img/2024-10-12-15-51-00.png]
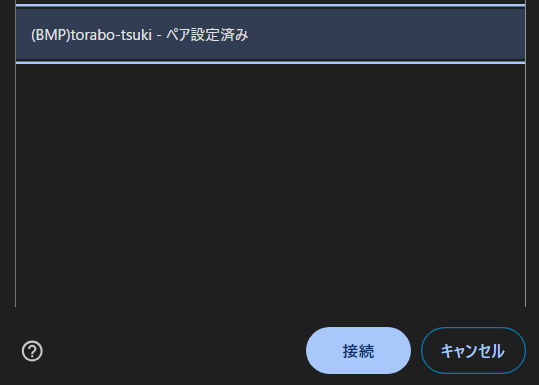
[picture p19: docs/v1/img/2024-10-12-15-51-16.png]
|||
|-|-|
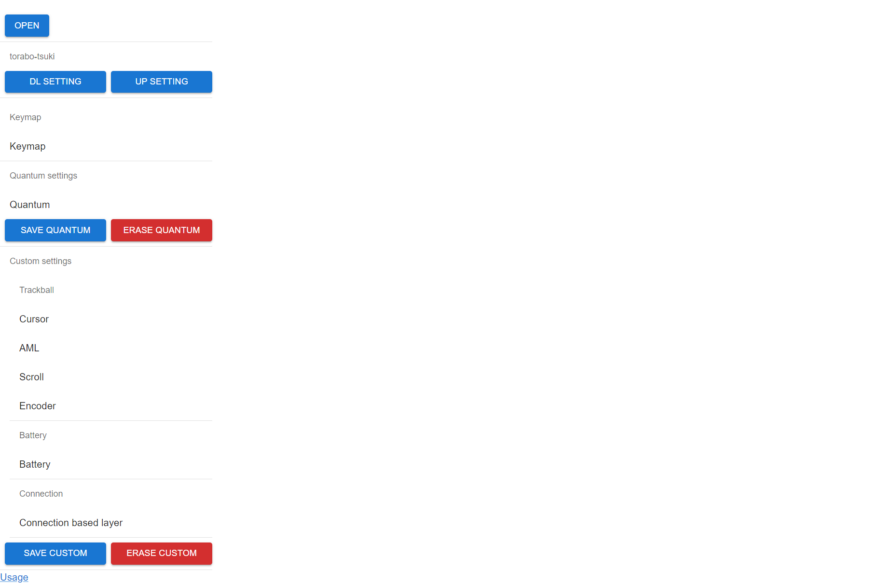
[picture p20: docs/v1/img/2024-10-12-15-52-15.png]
||

`Keymap`を選択すると画面右側にキーのレイアウトが表示されます。

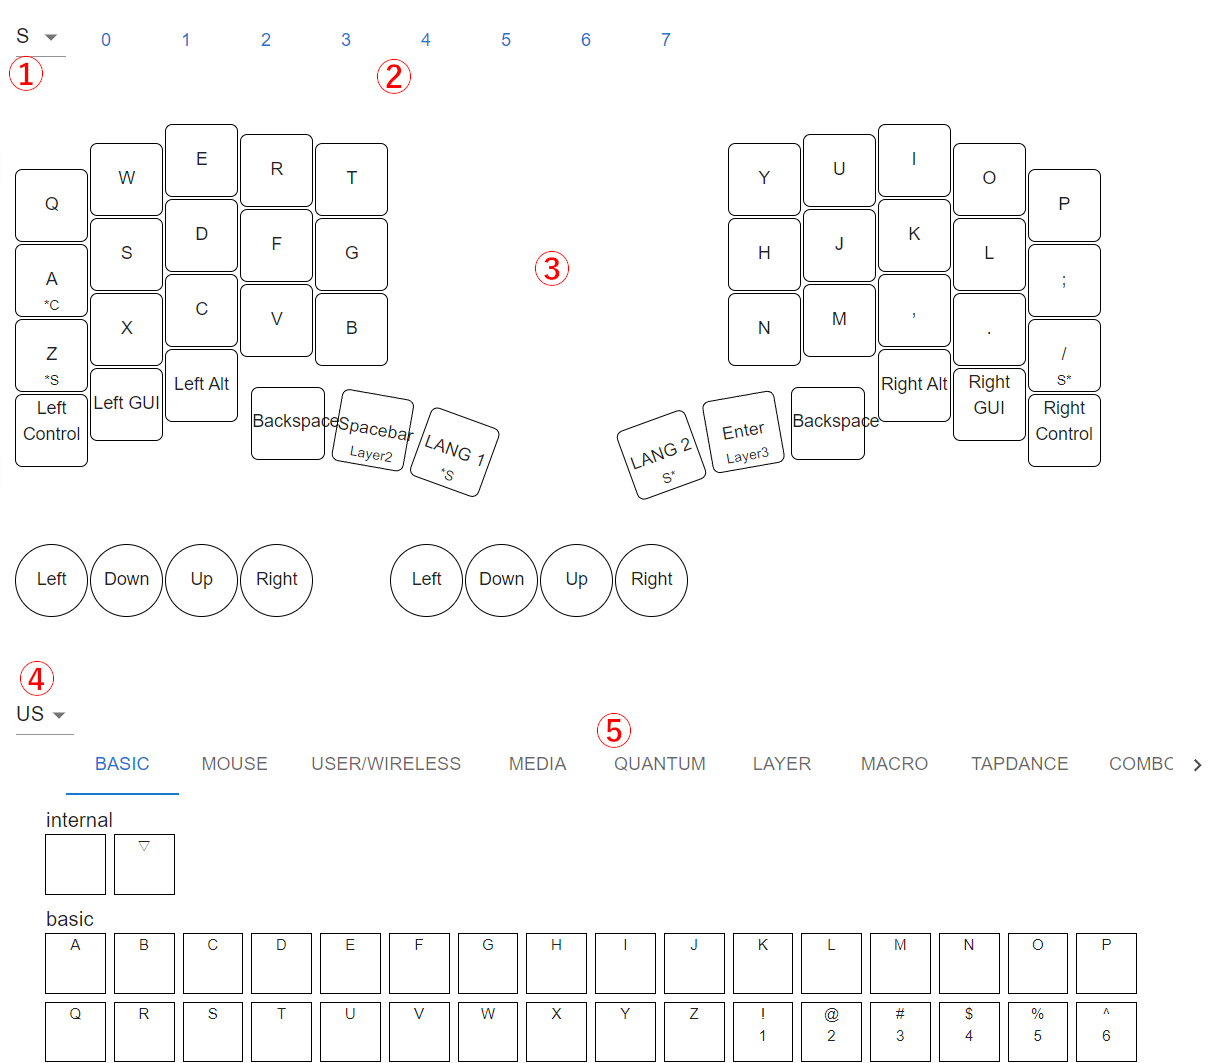
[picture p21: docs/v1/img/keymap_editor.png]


|番号|機能|
|-|-|
|1|レイアウト選択|
|2|レイヤー選択|
|3|キーマップ|
|4|キーリストの言語切り替え|
|5|キーリスト|

キーリストからキーをドラッグアンドドロップするか、キーマップ中のキーをクリックして表示されるポップアップで編集するとキーマップを書き換えられます。書き換え内容は変更した時点で保存されます。

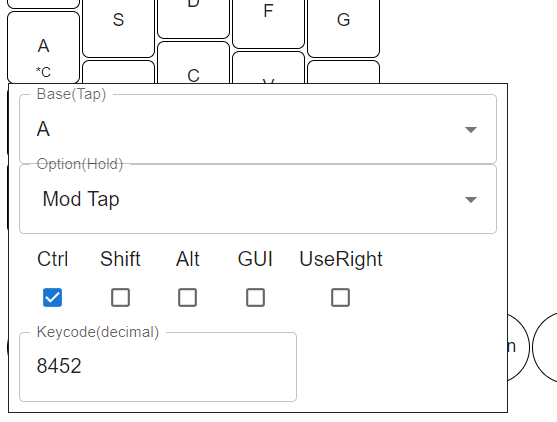
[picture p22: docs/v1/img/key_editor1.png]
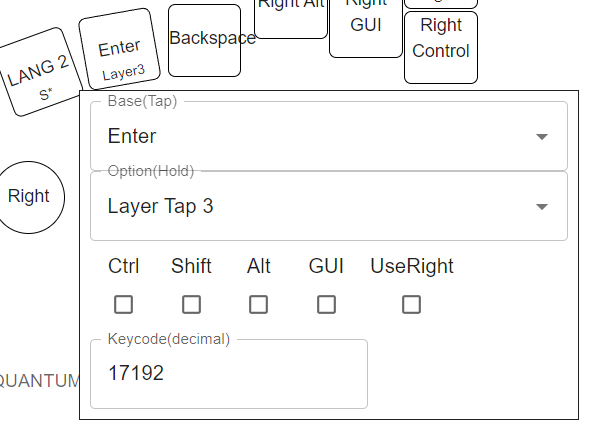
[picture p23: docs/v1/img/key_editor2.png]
|||
|-|-|

キーリストの`User/Wireless`タブには、BLE Micro Pro用に無線接続関連などいくつかのカスタムキーコードが組み込まれています。最低限、以下のキーコードをキーマップに設定することをおすすめします
  - Remapでは`BMP`タブまたは`FUNCTIONS`タブの`VIA USER KEY`からこれらのキーが設定できます
  - Vialでは`User`タブからこれらのキーが設定できます

  |キーコード|機能|
  |-|-|
  |AD_WO_L|ホストの接続、スレーブの探索を開始する。新しいデバイスとペアリングできる|
  |ADV_IDn|n番目にペアリングしたデバイスと接続しようとする|
  |SEL_USB|USB接続を経由して送信する|
  |SEL_BLE|BLE接続を経由して送信する|
  |BATT_LV|バッテリーの電圧を表示する(文字列が自動で入力されます)|
  |ENT_SLP|スリープモードに入る|
  |EN_WEBBT(QK_KB25)|無線経由でのキーマップ書き換えを有効化（1.4.0以降, スマホにも対応）|
  |DIS_WEBBT(QK_KB26)|無線経由でのキーマップ書き換えを有効化（1.4.0以降, スマホにも対応）|

  その他のカスタムキーコードとして、英語キーボードを日本語OSで動作させるためのオーバーライド(UJ OVR)や、日本語キーボードを英語OSで動作させるためのオーバーライド(JU OVR)にも対応しています。

  EN_WEBBTを押すとスマホやタブレットでもキーマップが書き換えられるモードになります。このモードの間は通常のキー入力はできないので、キーマップ書き換えが終わったら`DIS_WEBBT`でモードを抜けるか、電源を入れ直してください。

  safariはWeb bluetoothに対応していないのでbluefyを使用してください。

#### キーマップ設定の変更

`Quantum`メニューから、Tapping termなどQMKのキーマップ設定が変更できます。設定変更後、`Save Quantum`ボタンをクリックすると保存されます。各メニューの詳細についてはVialおよびQMKのドキュメントを参照してください。

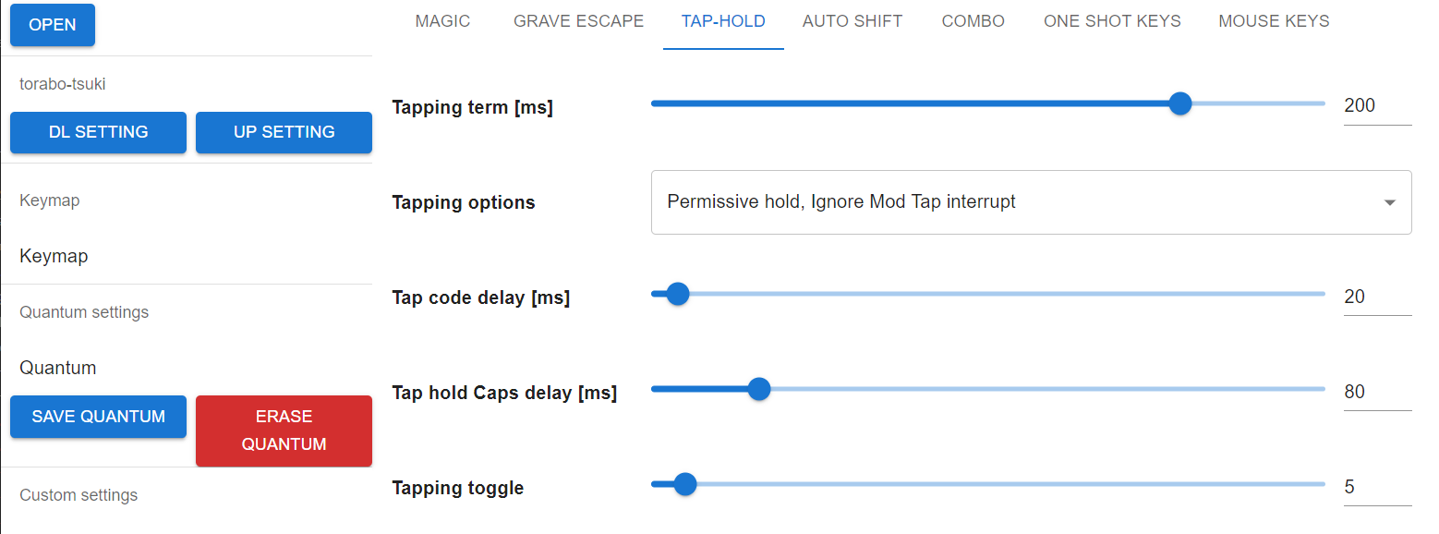
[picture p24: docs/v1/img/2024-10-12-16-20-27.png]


`Custom settings`で変更した設定は`Save Custom`ボタンをクリックすると保存されます。
`Connection based layer`を有効にすると無線接続先ごとにデフォルトレイヤーを変更できます。

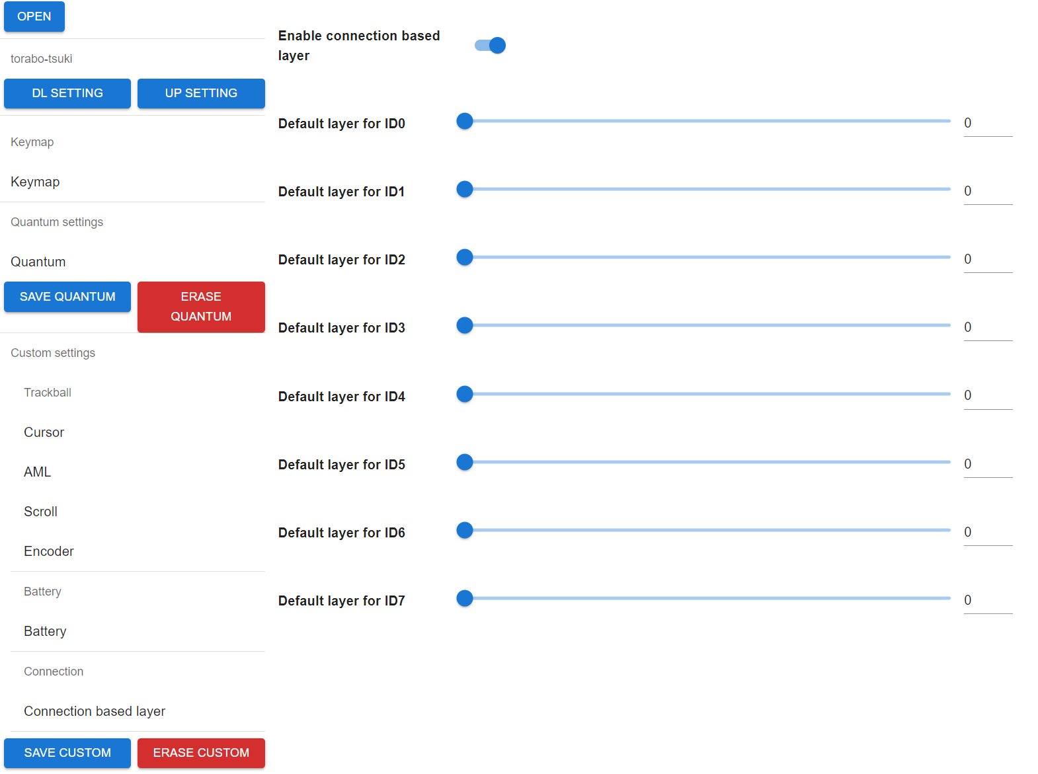
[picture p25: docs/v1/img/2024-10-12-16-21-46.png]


### ペアリングする

#### (分割型のみ)マスターとスレーブの接続

左右間のペアリングは両手の電源がONしてから数秒間のみ行われます。マスター側の電源を入れてから数秒以内にスレーブ側の電源を入れてください。

#### パソコン等とのペアリング

- キーボード起動直後から数秒間、または`AD_WO_L`を配置したキーを押下するとBLE Micro Proがアドバタイズを開始します。その後、ペアリングしたい機器からスキャンを実行して、キーボードが表示されたら選択して登録してください。
  - 2台目以降のデバイスとペアリングする場合は、他のペアリング済みデバイスのBluetoothを無効化してから`AD_WO_L`を実行してください。
  - 指定したペアリング済みパソコン等に接続したい場合、`ADV_IDx`を実行します。`x`はペアリング番号(0-7)です。分割型の場合、ID0はスレーブです。

ペアリングに関するトラブルの解決には再ペアリングが有効です。手順は[FAQ](FAQ.md)を参照してください。

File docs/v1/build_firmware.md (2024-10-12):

# ファームウェアをビルドする

- [環境構築](#環境構築)
  - [ファームウェアのリポジトリをクローンする](#ファームウェアのリポジトリをクローンする)
- [ビルドする](#ビルドする)
  - [uf2ファイルを生成する](#uf2ファイルを生成する)
- [生成したファームウェアを書き込む](#生成したファームウェアを書き込む)
  - [ブートローダの起動](#ブートローダの起動)
  - [ファームウェアの書き込み](#ファームウェアの書き込み)
- [設定ファイルの書き込み](#設定ファイルの書き込み)

## 環境構築

導入手順はQMKとほとんど同様です。基本的にはQMKの導入手順にしたがって必要ソフトをインストールしてください。

### ファームウェアのリポジトリをクローンする

- QMK公式のqmk_firmwareリポジトリとは別にBLE Micro Pro用のリポジトリをクローンする必要があります。
- ここでは `qmk_firmware_bmp_vial` という名前でクローンします。

``` 
git clone --depth 1 -b dev/ble-micro-pro https://github.com/sekigon-gonnoc/vial-qmk.git qmk_firmware_bmp_vial
```

uf2ではなくnrfutilを使って書き込む場合、追加でnrfutilをインストールします。

```
pip install nrfutil --user
```

## ビルドする

### uf2ファイルを生成する

以下のコマンドでuf2ファイルが生成されます。

```
make ble_micro_pro:vial:uf2
```

## 生成したファームウェアを書き込む

### ブートローダの起動

- キーボードのリセットボタンを押しながらUSB接続するとブートローダが起動します
- すでにキーボードとして動作する場合には[CLI](cli.md)からdfuコマンドを送信することでも起動できます  

### ファームウェアの書き込み

拡張子が`.uf2`のファイルを使って書き込みます

- BLE Micro Proがマスストレージデバイスとして認識され、中に`INFO_UF2.TXT`があることを確認してください。このファイルがない場合、ブートローダの起動に失敗しているので再起動してください
- アップデートしたいuf2ファイルをコピーするとアップデートが始まります。アップデート中はケーブルを外さないでください
- 書き込みが完了したら一度PCから取り外してください
- 再度マウントするとuf2ファイルは消えていますが、`VERSION.TXT`を開いてアップデート完了を確認してください

## 設定ファイルの書き込み

BLE Micro Proがアプリケーションを起動している状態で設定ファイルをコピーすると自動的に書き込みが始まります。

|ファイル名|R/W|役割|
|-|-|-|
|CONFIG.BIN|RW|キーボードの設定やVialの設定・バックアップ用|
|DEFAULT.BIN|RW|EEPROMのデフォルト状態(デフォルトキーマップなど)の設定・バックアップ用|
|EEPROM.BIN|R|現在のEEPROM状態のバックアップ用|
|VERSION.TXT|R|現在のファームウェアのバージョン|
|VIALJSON.BIN|R|vial.jsonを7zで圧縮したバイナリのバックアップ用|

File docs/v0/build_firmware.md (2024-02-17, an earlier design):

# ファームウェアをビルドする

**このページは旧バージョンのファームウェアについての説明です。最新版ファームウェアの説明は[こちら](../v1/README.md)**

- [環境構築](#環境構築)
  - [ファームウェアのリポジトリをクローンする](#ファームウェアのリポジトリをクローンする)
  - [必要なツールをインストールする](#必要なツールをインストールする)
- [ビルドする](#ビルドする)
  - [uf2ファイルを生成する](#uf2ファイルを生成する)
- [生成したファームウェアを書き込む](#生成したファームウェアを書き込む)
  - [(参考)nrfutilで書き込む場合](#参考nrfutilで書き込む場合)
- [新しいキーボードのフォルダをつくる](#新しいキーボードのフォルダをつくる)
- [カスタムキーコードを追加する](#カスタムキーコードを追加する)

## 環境構築

導入手順はQMKとほとんど同様です。基本的にはQMKの導入手順にしたがって必要ソフトをインストールしてください。

### ファームウェアのリポジトリをクローンする

- QMK公式のqmk_firmwareリポジトリとは別にBLE Micro Pro用のリポジトリをクローンする必要があります。
- ここでは `qmk_firmware_bmp` という名前でクローンします。

``` 
git clone --depth 1 -b dev/ble_micro_pro https://github.com/sekigon-gonnoc/qmk_firmware.git qmk_firmware_bmp
```

### 必要なツールをインストールする

以下のコマンドを実行してビルドに必要なツールをインストールします。

```
cd qmk_firmware_bmp
./util/qmk_install.sh
```

QMK公式とは異なりsubmoduleのlufaやChibiOSには依存していないため、`make git-submodules`は実行する必要がありません。

uf2ではなくnrfutilを使って書き込む場合、追加でnrfutilもインストールします。
```
pip install nrfutil --user
```

## ビルドする

### uf2ファイルを生成する

以下のコマンドでuf2ファイルが生成されます。

```
make ble_micro_pro:default:uf2
```

後述の方法で新しく定義したキーボードをビルドする場合は以下の形式になります。

```
make <keyboard>:<keymap>:uf2
```

## 生成したファームウェアを書き込む

ブートローダを起動してください。ブートローダの起動は以下のいずれかにより行えます。

- リセットボタンを押しながらUSBケーブルで接続する
- [CLI](cli.md)からdfuコマンドを発行する
- リセットボタンを長押しする（ver0.4から）

ブートローダを起動すると外部メディアとして認識されます。外部メディアは `BLEMICROPRO` という名前です。
この外部メディアに生成されたuf2ファイルをコピーすることでファームウェアがアップデートされます。

### (参考)nrfutilで書き込む場合

uf2ファイルを生成する代わりに以下のコマンドを実行します。

```
make ble_micro_pro:<keymap>:nrfutil
```

出力を読んでnrfutil用のzipファイルが生成され書き込み待機状態になったことを確認したら、BLE Micro Proのブートローダを起動します。
ブートローダを起動する方法は以下のいずれかです。

- リセットボタンを押しながらUSBケーブルで接続する
- [CLI](cli.md)からdfuコマンドを発行する
- リセットボタンを長押しする（ver0.4から）

## 新しいキーボードのフォルダをつくる

既存のフォルダ(`ble_micro_pro`など)をコピーするか、以下のスクリプトを使って用意してください。

```
$ ./util/new_keyboard.sh
Generating a new QMK keyboard directory

Keyboard Name: <your keyboard name>
Keyboard Type [avr]: nrf
Your Name [sekigon-gonnoc]: 

Copying base template files... done
Copying nrf template files... done
Renaming keyboard files... done
Replacing %YEAR% with 2019... done
Replacing %KEYBOARD% with name... done
Replacing %YOUR_NAME% with sekigon-gonnoc... done

Created a new keyboard called name.

To start working on things, cd into keyboards/name,
or open the directory in your favourite text editor.
```

## カスタムキーコードを追加する

QMK Firmwareのカスタムキーコードのページを参考に、keymap.cに追加します。
KEYMAP.JSNから指定できるようにするには、`custum_keys_user`にカスタムキーコードとそれを表す文字列を追加してください。

メンバ名|役割
---|---
start_kc|最初のカスタムキーコードの値
end_kc|最後のカスタムキーコードの値
key_strings|カスタムキーコードを表す文字列。`'\0'`で区切って順番に追加してください

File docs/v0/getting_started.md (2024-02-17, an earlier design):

# 自作キーボードキットを無線化する

**このページは旧バージョンのファームウェアについての説明です。最新版ファームウェアの説明は[こちら](../v1/README.md)**

BLE Micro Proを導入する手順はいくつかありますが、初めての場合は[BLE Micro Pro Web Configurator](https://sekigon-gonnoc.github.io/BLE-Micro-Pro-WebConfigurator/legacy)を使った方法がおすすめです。

- [ハードウェアの準備](#ハードウェアの準備)
- [BLE Micro Pro Web Configuratorを使う](#ble-micro-pro-web-configuratorを使う)
  - [事前準備](#事前準備)
  - [キーボードを選ぶ](#キーボードを選ぶ)
  - [ファームウェアのアップデート](#ファームウェアのアップデート)
  - [設定ファイルの書き込み](#設定ファイルの書き込み)
  - [キーマップの書き込み](#キーマップの書き込み)
    - [Remapを使う場合(USB接続)](#remapを使う場合usb接続)
    - [QMK Configuratorを使う場合(USB接続)](#qmk-configuratorを使う場合usb接続)
    - [QMK Configuratorを使う場合(BLE接続)](#qmk-configuratorを使う場合ble接続)
    - [VIA Configuratorを使う場合(非推奨)](#via-configuratorを使う場合非推奨)
  - [ペアリングする](#ペアリングする)
    - [(分割型のみ)マスターとスレーブの接続](#分割型のみマスターとスレーブの接続)
    - [パソコン等とのペアリング](#パソコン等とのペアリング)
- [BLE Micro Pro上のファイルを直接操作する](#ble-micro-pro上のファイルを直接操作する)
  - [UF2ファイルでファームウェアをアップデートする](#uf2ファイルでファームウェアをアップデートする)
    - [ブートローダの起動](#ブートローダの起動)
    - [ファームウェアの書き込み](#ファームウェアの書き込み)
  - [設定ファイルの書き込み](#設定ファイルの書き込み-1)
  - [設定ファイルの削除](#設定ファイルの削除)

## ハードウェアの準備

- BLE Micro Proを取り付ける準備
  - BLE Micro ProはPro Microの代わりに取り付けられます。
  - ピンヘッダでなくコンスルーを使う場合ははんだ付けは必要ありません([遊舎工房販売ページ](https://yushakobo.jp/shop/a01mc-00/), [TALP keyboard販売ページ](https://talpkeyboard.stores.jp/items/5e056626d790db16e2889233), [Switch Science 販売ページ](https://www.switch-science.com/catalog/3763/))
    - BLE Micro Proはコンスルー対応なのでBLE Micro Pro側にはんだづけが必要ありません。
    - Pro Microはコンスルー非対応なので、Pro Micro側にはんだ付けが必要です。
    - 国内キーボード基板はコンスルー対応基板が多いですが、海外キーボード基板の場合は非対応の場合が多く、キーボード基板側をはんだ付けする必要があります。
  - キーボード基板に電源ピンが用意されている場合は13ピンのコンスルーが必要な場合があります。キーボードキットの必要部品をよく確認してください。
    - 7skbやKugel-1のように、USBコネクタ側に寄せてコンスルーを取り付けることで12ピンでも動作するキットもあります。
  - キーボード基板に電源ピンが用意されていない場合は12ピンのコンスルーを調達してください。
    - BLE micro pro対応を明示していないキーボードの場合はこちらの可能性が高いです。

- 電源の準備
  - 導入の段階ではUSBケーブルで接続をしてUSB端子から電源供給を受けるので必須ではありません。
  - 無線運用するときには電池かそれに相当するものから電源供給する必要があります。
  - BLE Micro Pro用に設計されたものとしては単4電池基板([BOOTH販売ページ](https://nogikes.booth.pm/items/2710739))またはコイン電池基板([遊舎工房販売ページ](https://yushakobo.jp/shop/ble-micro-pro-battery-board/)、[BOOTH販売ページ](https://nogikes.booth.pm/items/1655285))があります。  
    - 電池基板とBLE Micro Proの接続にはコンスルー、ピンヘッダもしくは銅線を使ってください。
    - キーボードキットによってはキーボード上に電池基板に相当する機能を取り付けられるオプションがあります。そのオプションを使う場合は電池基板は不要です。
  - 電源を自分で作る場合には[デザインガイド](design_guide.md#電源)を参照してください。

## BLE Micro Pro Web Configuratorを使う

Google ChromeからBLE Micro Pro Web Configuratorにアクセスするとブラウザからファームウェアのアップデートや各種設定ができます。  
* ブラウザに依存するトラブルを避けるためその他のChromium系ブラウザではなくChromeを使ってください

### 事前準備

Google Chromeを起動して、 [Web Configurator](https://sekigon-gonnoc.github.io/BLE-Micro-Pro-WebConfigurator/legacy) にアクセスしてください。

Chrome 89 Stableから、特にChromeの設定を変更することなく、Web Configuratorを利用することができるようになりました。もし Chrome 89 Stable 以前のバージョンをお使いの際には、Chromeのアドレスバーに `chrome://flags#enable-experimental-web-platform-features`を入力して、**Experimental Web Platform featuresをEnabled**にしてください。

### キーボードを選ぶ

`ナビゲーション付きでセットアップを開始する`ボタンを押すとキーボードの選択画面が表示されます。
リストから無線化したいキーボードを選んでください。

ErgoDashやRunner3680のようにキー配置が複数選べる場合はレイアウトが選択できるので、自分が作ったキーボードのレイアウトを選択してください。

無線化したいキーボードがリストにない場合には、[キーボードの設定を生成して](edit_config_file.md)、ここでは`ble_micro_pro`または`ble_micro_pro_split`を選択してください。

このページでは2つのオプションが選択できます。

- Disable Mass Storage Class
  - BLE Micro Proにファームウェアを書き込むとパソコンにUSBケーブルで接続したときに大容量記憶デバイスとして認識されます。セキュリティの都合などで、大容量記憶デバイスとして認識されると困る場合にはこのオプションにチェックを入れることで機能を無効化できます。

- Use with LPME-IO（分割型のみ）
  - 分割型キーボードを無線化するときにBLE Micro Proを2台使った完全無線化をするのではなく、BLE Micro ProとLPME-IOを組み合わせた部分無線化をする場合にはこのオプションにチェックを入れてください。  
  - **LPME-IOを使用するにはキーボードの改造が必要な場合があります**

構成を選択し終わったら`Next`ボタンを押すと次の手順に進みます。

### ファームウェアのアップデート

BLE Micro Proにはブートローダとアプリケーションという2種類のファームウェアを書き込みます。

2つのファームウェアのバージョンは`<major>.<minor>.<revision>`の3つの数字の組み合わせで表されていて、ブートローダとアプリケーションのメジャーバージョンとマイナーバージョンは一致させる必要があります。

特別な事情がない限りは両方ともデフォルトで選択されている最新版を利用してください。

また、大容量記憶デバイスの無効化オプションはブートローダとアプリケーションのそれぞれで設定でき、初期設定は最初の画面で選んだとおりになっています。

アップデートしたいBLE Micro ProをUSBケーブルで接続したら、`Update`ボタンを押してください。
[事前準備](#事前準備)が終わっていれば、ブラウザの左上からCOMポートの選択画面が表示されます。
BLE Micro ProのCOMポートを選択したら`接続`ボタンを押してください。
どのポートがBLE Micro Proのものかわからない場合は、接続する前後で比較してみてください。

ブートローダが起動したという表示が出た場合はもう一度`Update`ボタンを押します。

アップデートが始まると進捗状況が表示されます。進捗が100%になり、アップデートに成功したという表示が出たら`Next`ボタンを押して次の手順に進みます。

繰り返しになりますが、ブートローダとアプリケーションをそれぞれアップデートしてください。

### 設定ファイルの書き込み

設定ファイルの書き込み画面でもキーボードの選択リストが表示されます。
ナビゲーション付きでセットアップを開始した場合は最初に選択したキーボードとレイアウトが選択されているため、ここで選択し直す必要はありません。

最初にキーボードを選択するときに`ble_micro_pro`を選択した場合は、ここで`upload your own`を選択してください。

ここでもいくつかオプションを設定できます

- Use With LPME-IO（分割型のみ）
  - 前述の設定と同様です。デフォルトでは最初の画面で選んだ設定が引き継がれています。

- Is Slave（分割型のみ）
  - 分割型の場合、2つのBLE Micro ProにMaster/Slaveという役割が割り振られます。ナビゲーション付きでセットアップを開始した場合は手順に応じて自動的に選択されるため、変更する必要はありません。

- Is Left（分割型のみ）
  - いま設定しているBLE Micro Proを左手に取り付ける場合にはチェックを入れてください。

- Show keymap.json using JP_XX
  - キーマップ設定の表示を、OSの設定がJISキーボードとなっているときに適した表示にします。

- Debounce
  - キー入力のチャタリング除去のパラメータです。デフォルトは1で、チャタリングがひどい場合にはチャタリングが無くなるまで1ずつ増やしてみてください。

- Connection inteval(Peripheral)
  - 通信間隔の設定です。短くすると入力のラグが減る一方で、電力消費が増加します。
    - 一体型キーボード、または分割型キーボードのMasterを設定している場合はPCとの通信間隔を設定します。
    - 分割型キーボードのSlaveを設定している場合はMasterとの通信間隔を設定します。後述のMaster側の設定と合わせてください。
  
- Connection inteval(Central)（分割型Masterのみ）
  - 分割型キーボードのSlaverとの通信間隔を設定します。前述のSlave側の設定と合わせてください。

オプションを設定したら`Update`ボタンを押すとシリアルポートの選択が表示され、BLE Micro Proを接続したシリアルポートを選択するとアップデートが始まります。
リストから`upload your own`を選択した場合はここでファイルの選択画面が表示されるため、用意したコンフィグファイルを選んでください。
設定が成功したら`Next`ボタンを押して次の手順に進んでください。

一体型キーボード、またはLPME-IOを使った設定をしている場合はこのままキーマップの書き換えに進みます。

分割型キーボードを完全無線化する場合はSlave側のBLE Micro Proに繋ぎ変えて同様の手順を繰り返してください。

すべてのBLE Micro Proの設定が完了したら、Master側のBLE Micro Proに再度繋ぎ変えて、キーマップの書き換えに進んでください。

### キーマップの書き込み

Remap, QMK Configurator, VIA Configurator(非推奨)のいずれかでキーマップを変更します。
- 合計で489キー分の設定を保存できます。何レイヤにあたるかはキーボードによって異なります
  - Remap, VIAに接続すると設定できる最大レイヤと同じ数のレイヤが自動で表示されます。
  - QMK Configurator, KEYMAP.JSNを直接編集する場合、上限を超えたキーの設定は無視されます。
- Remapは拡張キーコードの設定に対応していません。
- キーボードの定義がRemapまたはQMK Configuratorのどちらかにしかない場合がありあます。一方に接続してうまく行かないときはもう一方も試してください。
  - またはRemapに設定用のjsonファイルをアップロードしてください。
- BLE Micro Pro用に無線接続関連など[いくつかのカスタムキーコード](edit_keymap_file.md#カスタムキーコード)が組み込まれています。最低限、以下のキーコードをキーマップに設定することをおすすめします

  |キーコード|機能|
  |-|-|
  |AD_WO_L|ホストの接続、スレーブの探索を開始する。新しいデバイスとペアリングできる|
  |ADV_IDn|n番目にペアリングしたデバイスと接続しようとする|
  |SEL_USB|USB接続を経由して送信する|
  |SEL_BLE|BLE接続を経由して送信する|
  |BATT_LV|バッテリーの電圧を表示する(文字列が自動で入力されます)|
  |ENT_SLP|スリープモードに入る|

#### Remapを使う場合(USB接続)

BLE Micro Proのバージョンがbootloader:0.9.3, firmware:0.9.4以上の場合、[Remap](https://remap-keys.app/)からキーマップを書き換えることができます。

はじめて設定する場合、キーマップはすべて`KC_NO`になってしまっています。Remapの共有機能でデフォルトキーマップが共有されている場合はそれを適用できます。
あるいは、有線版で組み立てたことがある場合はRemapのSAVE/RESTORE機能を使ってPro Microのキーマップを保存しておいてからBLE Micro Pro上に復元してください。

#### QMK Configuratorを使う場合(USB接続)

キーマップの書き換えにはBLE Micro Pro用の変更を加えた[QMK Configurator](https://sekigon-gonnoc.github.io/qmk_configurator/)を使います。

- `CONNECT BY SERIAL`ボタンを押してシリアルポートを開く。
  - 一度キーマップを設定済みのBLE Micro Proに接続した場合、自動的にBLE Micro Proから現在のキーマップがロードされます。
- はじめて設定する場合、キーボードリストから設定したいキーボードを選択してキーマップを設定する。
  - デフォルトキーマップが登録されている場合はそれが表示されます。されていない場合はすべて`KC_NO`になってしまっているので、自分で全部設定するか、Remapを試してみてください。
  - キーボードリストにキーボードがない場合、`CONNECT BY SERIAL`の右側にあるボタンを押してキーマップをロードするとconfig.jsonの中身に応じた暫定のキー配置でキーマップが表示されます。他のキーボードのようにレイアウトしたい場合はQMK Configurator(公式)にプルリクエストを出してください。
- `CONNECT BY SERIAL`の左側のボタンを押して設定したキーマップをキーボードに反映する。
- 試しに入力してみて問題なければ`SAVE KEYMAP`ボタンを押してキーボードに保存する。

以上でBLE Micro Proの設定は完了です。QMKの設定を変えたり、カスタムキーコードを追加したりしたい場合は[ファームウェアをビルドする](build_firmware.md)に進んでください。

#### QMK Configuratorを使う場合(BLE接続)

この方法は一度USB接続でキーマップを書き込んでから使えるようになります。

- [CLI](cli.md)から`web`コマンドを実行する、またはENT_WEBキーを押してConfiguratorモードを起動する。
  - ConfiguratorモードではBLE経由でのキー入力はできません
- `CONNECT BY BT`ボタンを押してシリアルポートを開く。
- `CONNECT BY BT`の右側のボタンを押してキーボードからキーマップをロードする。
- `CONNECT BY BT`の左側のボタンを押して設定したキーマップをキーボードに反映する。
  - BLE経由の場合は反映した時点で永続化されます

#### VIA Configuratorを使う場合(非推奨)

- VIA Configuratorからキーマップを変更できます。ただし、LEDの設定はできません。0.10.2以降ではマクロも設定できます。

- BLE Micro Pro用QMK Configuratorと違い、BLE Micro Pro用のキーコードが設定できず、また、レイヤを追加することもできません。

- 書き換えの方法はVIA Configuratorのマニュアルを参照してください。書き換えられたキーマップは一時的なものなので、永続化するにはInsertキーを5秒以上押してから離してください。

### ペアリングする

#### (分割型のみ)マスターとスレーブの接続

- 分割型の場合は、マスターとスレーブの起動直後にペアリングが自動で実行されます。マスター起動後速やかにスレーブを起動してください。
- パソコンとのペアリングを実行する前に、マスターをUSB接続した状態で両手とも入力できることを確認してください。

#### パソコン等とのペアリング

- `AD_WO_L`を配置したキーを押下するとBLE Micro Proがアドバタイズを開始します。その後、ペアリングしたい機器からスキャンを実行して、キーボードが表示されたら選択して登録してください。

- 2台目以降のデバイスとペアリングする場合は、他のペアリング済みデバイスのBluetoothを無効化してから`AD_WO_L`を実行してください。

- 指定したペアリング済みパソコン等に接続したい場合、`ADV_IDx`を実行します。`x`はペアリング番号(0-7)です。分割型の場合、ID0はスレーブです。

## BLE Micro Pro上のファイルを直接操作する

### UF2ファイルでファームウェアをアップデートする

#### ブートローダの起動

- キーボードのリセットボタンを押しながらUSB接続するとブートローダが起動します

- すでにキーボードとして動作する場合には[CLI](cli.md)からdfuコマンドを送信することでも起動できます  

- v0.4.0以降のQMK for BMPを使用している場合、起動中にリセットスイッチ長押しでも起動します

#### ファームウェアの書き込み

拡張子が`.uf2`のファイルを使って書き込みます  
**[ブートローダーv0.2.0, v0.3.0からアップデートする場合はv0.2.1, v0.3.1を経由してください](https://github.com/sekigon-gonnoc/BLE-Micro-Pro/issues/10)**  
nrfutilを使う場合は経由せずに直接アップデートできます

- BLE Micro Proがマスストレージデバイスとして認識され、中に`INFO_UF2.TXT`があることを確認してください。このファイルがない場合、ブートローダの起動に失敗しているので再起動してください
  - v0.4.0以降、ブートローダ起動時のボリュームラベルはBLEMICROPRO、キーボード起動時のボリュームラベルは設定したキーボード名になるので、これで判別することもできます

- アップデートしたいuf2ファイルをコピーするとアップデートが始まります。アップデート中はケーブルを外さないでください

- アップデートが完了すると自動でアンマウントされます

- 再度マウントするとuf2ファイルは消えていますが、下記の方法でアップデートが完了していることを確認してください

  - ブートローダをアップデートした場合、`INFO_UF2.TXT`を開いてアップデート完了を確認してください

  - アプリケーションのアップデートの場合は`VERSION.TXT`を開いてアップデート完了を確認してください

### 設定ファイルの書き込み

BLE Micro Proがアプリケーションを起動している状態で設定ファイルをコピーすると自動的に書き込みが始まります。
BLE Micro Pro上のファイルを直接編集することもできますが、バックアップの意味も兼ねて一度PC上にコピーしてから編集、転送することを推奨します。

|ファイル名|役割|
|-|-|
|CONFIG.JSN|キーボードのマトリクスの割り当てなどを設定する|
|KEYAMP.JSN|キーマップを設定する|
|TAPTERM.JSN|TAPPING TERMを設定する|
|ENCODER.JSN|ロータリーエンコーダの割り当てを設定する|
|MACRO.TXT|マクロを設定する|
|VERSION.TXT|書き込まれているファームの情報を表示する|
|INDEX.HTM|ドキュメントへのリンク|
|MAP_EDIT.HTM|QMK Configuratorへのリンク|

コンフィグ用ファイル（CONFIG.JSN）は[BLE Micro Proのリポジトリから探す](https://github.com/sekigon-gonnoc/BLE-Micro-Pro/tree/master/AboutDefaultFirmware/keyboards)か、キーボードの作者が提供しているものを使うか、[自分で作成する](edit_config_file.md)か、いずれかの方法で用意してください。
なお、書き込むときにファイル名をCONFIG.JSNにリネームする必要はありません。再起動後に自動でリネームされます。

キーマップ用ファイル（KEYMAP.JSN）はQMK Configuratorを使って生成するか、テキストエディタなどで編集してください。
書き方は[こちら](edit_keymap_file.md)

TAPPING TERMの調整、ロータリーエンコーダの設定、マクロの設定については[こちら](edit_other_config_file.md)。

### 設定ファイルの削除

PCから見えているファイルを削除してもBLE Micro Proを再起動すると復活します。完全に削除してデフォルトに戻したい場合は[CLI](cli.md)からremoveコマンドを使ってください。

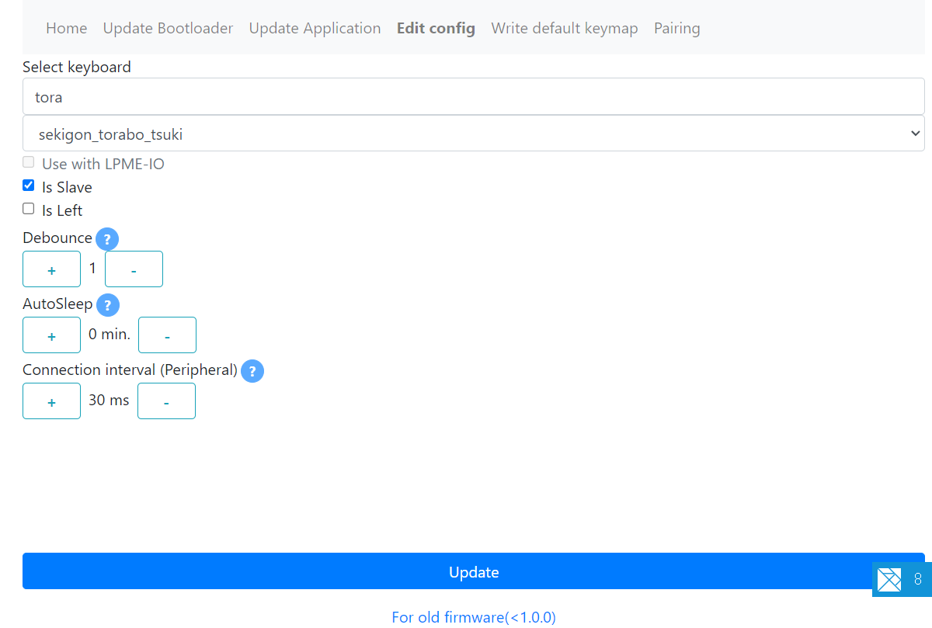
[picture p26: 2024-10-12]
docs/v1/img/step7.png

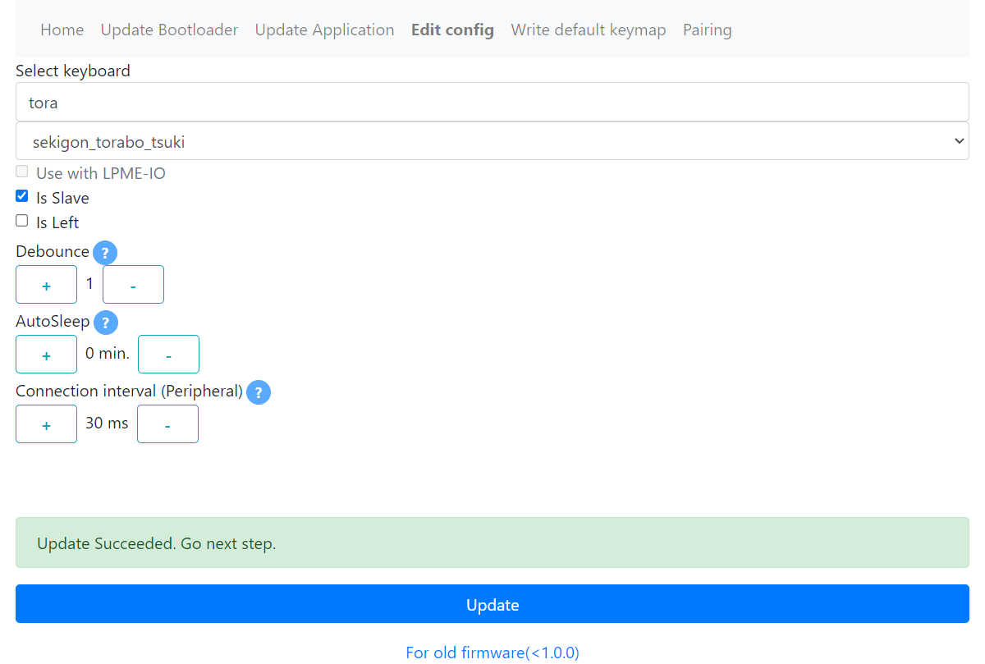
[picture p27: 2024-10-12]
docs/v1/img/step8.png

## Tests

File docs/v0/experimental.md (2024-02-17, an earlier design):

# 試験的な機能

**このページは旧バージョンのファームウェアについての説明です。最新版ファームウェアの説明は[こちら](../v1/README.md)**

現在開発段階の機能です。

- [Remap(\>QMK 0.19), Vial 対応](#remapqmk-019-vial-対応)
  - [BLE Miro Proを更新して設定ファイルを書き込む手順](#ble-miro-proを更新して設定ファイルを書き込む手順)
    - [BLE Micro Pro Web ConfiguratorでVial対応のファームウェアを書き込む](#ble-micro-pro-web-configuratorでvial対応のファームウェアを書き込む)
    - [bmp-vial対応の設定ファイルを用意する](#bmp-vial対応の設定ファイルを用意する)
    - [BLE Micro Proに設定ファイルを書き込む](#ble-micro-proに設定ファイルを書き込む)
  - [Remap, Vialでの設定変更方法](#remap-vialでの設定変更方法)
  - [BLE Miro Pro Web Configuratorに登録するための手順](#ble-miro-pro-web-configuratorに登録するための手順)
    - [デフォルトキーマップ用binファイルを用意する](#デフォルトキーマップ用binファイルを用意する)
    - [2種類のjsonファイルとデフォルトキーマップ用binファイルを登録する](#2種類のjsonファイルとデフォルトキーマップ用binファイルを登録する)
  - [ファームウェアをビルドする](#ファームウェアをビルドする)

## Remap(>QMK 0.19), Vial 対応

QMK 0.19以降の破壊的な変更に合わせて[Remap](https://remap-keys.app/)の仕様も大幅に変更されています。
BLE Micro Proもこの変更に対応するため、ファームウェアの更新をおこなっています。

この更新ではRemap(VIA)だけでなく[Vial](https://get.vial.today/)にも対応できるように設定ファイルの形式を変更します。そのため、従来使用していたCONFIG.JSNやKEYMAP.JSNの代わりとなる設定ファイルを用意していただく必要があります。
Vialはブラウザ上だけでなくローカル環境での実行ファイルも用意されています。また、キーレイアウトなどの情報をキーボード側に保持しており、ファームウェアのバージョンに応じてキーコード定義を切り替えるようになっています。今後に各種ファームウェアやツールの仕様変更があったとしても、ユーザーにキーボードファームウェアの更新を強制させないことが今回の変更の目的です。

### BLE Miro Proを更新して設定ファイルを書き込む手順

Vial対応のファームウェア(bmp-vial)の導入手順は以下の3ステップです。

1. [BLE Micro Pro Web Configurator](https://sekigon-gonnoc.github.io/BLE-Micro-Pro-WebConfigurator/#/home)でVial対応のファームウェア(`ble_micro_pro_bootloader_1_x_x` と `ble_micro_pro_vial_1_x_x`)を書き込む
1. bmp-vial対応の設定ファイルを用意する
1. BLE Micro Proに設定ファイルを書き込む 

#### BLE Micro Pro Web ConfiguratorでVial対応のファームウェアを書き込む

従来のファームウェアと同様にWebブラウザからファームウェアを更新できます。
bmp-vialではファームウェアのメジャーバージョンが1となっています。
そのため、ブートローダは `ble_micro_pro_bootloader_1_x_x` 系を、アプリケーションは `ble_micro_pro_vial_1_x_x` 系を書き込んでください。現時点ではMass Storage機能が有効なファームウェアしかないので、`Disable Mass Storage Class`のチェックボックスは必ず外してください。

現時点では設定ファイルをWebブラウザから書き込めないためEdit Configのページはスキップしてください。

#### bmp-vial対応の設定ファイルを用意する

従来の設定ファイルが用意されていたキーボードのうち、QMK公式にinfo.jsonが存在しているか、こちらでinfo.jsonの所在を把握していたキーボードについては[Release](https://github.com/sekigon-gonnoc/BLE-Micro-Pro/releases/tag/bmp-vial-1.0.0-rc)ページに書き込み用設定ファイルを、[github](https://github.com/sekigon-gonnoc/BLE-Micro-Pro/tree/master/bmp-vial-config)に 書き込み用ファイルの元となったjsonファイルを用意しています。

それ以外のキーボードや修正が必要な場合は下記の手順に沿って設定ファイルを用意してください。
設定ファイルは下記の3種類必要です。

* vial用jsonファイル(vial.json)
  * vial用の設定ファイルです
* config用jsonファイル(config.json)
  * BLE Micro Pro用の設定ファイルです。従来とは一部の項目が変わっています
* 書き込み用binファイル(config.bin)
  * vial.jsonとconfig.jsonから生成された書き込み用のバイナリファイルです

設定ファイルは[bmp-vial-config-generator](https://sekigon-gonnoc.github.io/bmp-vial-config-generator/)を利用して生成できます。

1. 左側のテキストボックスにQMKのinfo.jsonを記入する
   1. QMK公式のリポジトリにinfo.jsonが存在する場合はテキストボックス下部にあるリストから選択できます。
2. 左下の`Generate`ボタンをクリックしてvial.jsonとconfig.binを生成する
   1. 自動生成されたvial.jsonでは内容が不十分な場合はテキストボックスの中身を書き換えてください
3. 中央下の`Append BMP custom keycodes`ボタンをクリックして、BLE Micro Pro用のカスタムキーコードリストをvial.jsonに追加する
4. `Download vial.json`ボタンをクリックしてvial.jsonをダウンロードする
5. 分割キーボードの場合は右下のリストからconfig.jsonの対象(master, slave, lpme)を選択する
6. `Download config.json`ボタンをクリックしてconfig.jsonをダウンロードする
7. `Downliad config.bin`ボタンをクリックしてconfig.binをダウンロードする

#### BLE Micro Proに設定ファイルを書き込む 

1. BLE Micro Proのアプリケーションが起動していることを確認する
   1. マスストレージとして認識されているBLE Miro Proを開き、中にCONFIG.BINがあることを確認する
2. 用意したconfig.binをドラッグアンドドロップして書き込む（ファイル名は任意）
3. 書き込み完了後に電源を再投入して、デバイス名が書き込んだキーボードに変わっていることを確認する

### Remap, Vialでの設定変更方法

* Remapは従来通りの方法で利用できます
* Vialを利用する場合、ローカル版のVialでは電源投入後の初回の接続には必ず失敗してしまいます。エラーが表示されたらRefreshボタンを押して再読み込みしてください。ブラウザ版では自動でリトライされるため、再読み込みの操作は必要ありません
* 一度Vialと接続した場合、リセットするまでRemapには接続できなくなります。Remapに再接続したい場合は、リセットするか電源を再投入してください
* Remapのマクロ定義とVialのマクロ定義が異なるため、一方で編集したマクロはもう一方で正しく表示されない場合があります。どちらで定義してもマクロの実行は可能です

### BLE Miro Pro Web Configuratorに登録するための手順

Vial対応の設定ファイルをBLE Micro Pro Web Configuratorに登録したい方は追加で以下の手順の実施をお願いします。該当キーボードの作者以外の方でもプルリクエストを作成していただいて構いません。

1. デフォルトキーマップ用binファイルを用意する
2. 2種類のjsonファイルとデフォルトキーマップ用binファイルを登録する

#### デフォルトキーマップ用binファイルを用意する

EEPROMリセット時に反映されるデフォルトキーマップを各キーボードに合わせるための設定ファイルを用意してください。

1. RemapまたはVialを使ってデフォルトにしたいキーマップをキーボードに書き込む
2. BLE Micro Proのマスストレージを開きEEPROM.BINをPCにコピーする
3. コピーしたEEPROM.BINの名前を変更する
   1. 名前はキーボード設定用のconfig.binに合わせて`<キーボード名>_default.bin`としてください
4. ファイルをBLE Micro Proに書き戻し、EEPROMをリセットしたときに意図通りのキーマップになっていることを確認する

#### 2種類のjsonファイルとデフォルトキーマップ用binファイルを登録する

BLE Miro Proのリポジトリの `bmp-vial-config/` にvial.json, config.json, default.binファイルを追加してプルリクエストを作成してください。

### ファームウェアをビルドする

デフォルトのファームウェアに変更を加えたい場合は[リポジトリ](https://github.com/sekigon-gonnoc/vial-qmk)からソースコードを取得してビルドしてください。

```
make ble_micro_pro:vial:uf2 
```

でき上がったuf2ファイルをブートローダ状態のBLE Micro Proにドラッグアンドドロップすることで書き込めます

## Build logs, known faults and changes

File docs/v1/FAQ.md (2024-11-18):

# FAQ

## 電池はどれくらい持ちますか

- 使い方や電池の種類によります。
  - 消費電流は打鍵時で\~300uA(一体型の場合\~150uA)、待機時で\~100uAくらいです。
    - CR1632を2個使って分割型のキーボードを無線化する場合、計算上は約1000時間打鍵できます。
 
## ペアリング台数は何台ですか

- 一体型の場合は8台、分割型の場合は7台まで接続できます。

## CONFIG.JSNが反映されない

- [セーフモード](safemode.md)になっていませんか？

## 入力にラグを感じる

- コンフィグファイルの接続パラメータを短くしてみてください。

- また、接続先デバイスの省電力設定等も見直してください。

## 30秒くらい入力しないとそれ以降入力できなくなる

- 他のデバイス(OS)でも再現しますか？ 再現しない場合はOSの省電力設定が怪しいかもしれません

## PC等との接続が上手くいかなくなった

- PC等の側から一度ペアリングを解除し、もう一度ペアリングしてください。

- それでもうまく行かない場合は、PCとBLE Micro Proの両方からペアリング情報を削除してから再接続してください。
  - Master側の[CLI](cli.md)から`show`コマンドを実行し、接続先のIDを確認してください。
  - `del <slave id>`コマンドでPCとのペアリングを削除してから`adv`コマンドを実行し、再ペアリングしてください。

## Slave側が入力できない

- Master側の[CLI](cli.md)から`show`コマンドを実行し、SlaveのIDを確認してください。

- `del <slave id>`コマンドでSlaveとのペアリングを削除してから`adv`コマンドを実行し、Slaveと再ペアリングしてください。

- それでもうまく行かない場合は、MasterとSlaveの両方からペアリングを削除し、再ペアリングを試みてください。

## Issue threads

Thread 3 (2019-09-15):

ブランチ名が間違っている？

elfmimi, 2019-09-15:
AboutDefaultFirmware/doc/build_bmp_qmk_firmware.md に

> git clone --depth 1 -b nrf52/ble_micro_pro https://github.com/sekigon-gonnoc/qmk_firmware.git qmk_firmware_bmp

とあるのですが
-b dev/ble_micro_pro
の間違いでしょうか？ (それともブランチ名の改名をする予定だったか。)

sekigon-gonnoc, 2019-09-16:
`-b dev/ble_micro_pro`に修正しました

Closed 2019-09-16.

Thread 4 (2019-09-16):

apidef.h が無い

elfmimi, 2019-09-16:
以下で include されている apidef.h が存在しないためビルドできません。
https://github.com/sekigon-gonnoc/qmk_firmware/blob/c932f946dab7be602846190d3eb30127ceadf114/tmk_core/protocol/nrf/sdk15/apidef.h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

bootloader のアーカイブに含まれているかと考えて探したのですが見つけられませんでした。
https://github.com/sekigon-gonnoc/BLE-Micro-Pro/blob/master/AboutDefaultFirmware/ble_micro_pro_bootloader.zip

sekigon-gonnoc, 2019-09-16:
修正しました
sekigon-gonnoc/qmk_firmware@b180c463

Closed 2019-09-16.

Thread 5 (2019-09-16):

ビルドガイドの標準のビルド対象について

elfmimi, 2019-09-16:
ビルドの仕方の案内
https://github.com/sekigon-gonnoc/BLE-Micro-Pro/blob/master/AboutDefaultFirmware/doc/build_bmp_qmk_firmware.md
に

> make &lt;keyboard&gt;:&lt;keymap&gt;:nrfutil

とありますが

> make ble_micro_pro:default:nrfutil

で良いのではないでしょうか？

sekigon-gonnoc, 2019-09-16:
反映しました

Closed 2019-09-16.

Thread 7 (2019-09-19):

キーコード LCTL_T(KC_TAB)でタップでもプレスでもKC_LCTLが入力される

hatanoh, 2019-09-19:
KEYMAP.JSNの読み込みでもLCTL_T(KC_TAB)で読めるので、パースは成功しているように見える。
ただし、タップでKC_TABが入力されない。
LSFT_T / RCTL_T でも同様にタップでKCが入力されない。

sekigon-gonnoc, 2019-09-20:
現在のファームウェアだとソースコード中で設定したTAPPING_TERMは無視されて０になってしまうようです。TAPTERM.JSNにタッピングタームを指定してください。
https://github.com/sekigon-gonnoc/BLE-Micro-Pro/blob/master/AboutDefaultFirmware/doc/getting_start.md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

Closed 2019-09-20.

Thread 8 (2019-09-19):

const key_string_map_t custom_keys_user で最初に登録したキーコードがjsonファイルでは空白になる

hatanoh, 2019-09-19:
const key_string_map_t custom_keys_user =
{
    .start_kc = NORM,
    .end_kc= cKANA,
    .key_strings =
    "NORM\0ALTN\0"
    "SEL_BLE\0SEL_USB\0TOG_HID\0"
    "xEISU\0xKANA\0"
    "RAISE\0LOWER\0ADJUST\0CONFIG\0"
    "rSPC\0lENT\0lEISU\0lKANA\0cEISU\0cKANA\0"
};
としたとき、KEYMAP.JSN にNORMと書いた箇所が、KEYMAP.JSNを読み出すと""になっている。
NORMのキーコード自体は認識されているようなので、内部テーブルからKEYMAP.JSNを作る時に失敗していそう。

sekigon-gonnoc, 2019-09-20:
修正しました

Closed 2019-09-20.

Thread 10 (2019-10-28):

ブートローダアップデート後にアプリケーションが起動しない

sekigon-gonnoc, 2019-10-28:
## 発生条件
- ブートローダをuf2ファイルでアップデートする
- バージョン0.2.0, 0.3.0で確認

sekigon-gonnoc, 2019-10-28:
## 解決方法
- 0.2.1または0.3.1にアップデートしてからもう一度アップデートする
- nrfutilを使ってアップデートする

のいずれか
### 例
- 0.2.0から0.3.1にアップデートする場合
  - 0.2.0 -> 0.2.1 -> 0.3.1
- 0.3.0から0.3.1にアップデートする場合
  - 0.3.0 -> 0.3.1 -> 0.3.1

Closed 2019-10-28.

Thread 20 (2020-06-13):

Can't delete or change config.jsn and keymap.jsn

azat-dev, 2020-06-13:
Hi!

Could you help me please? I can't delete or change config files. It writes me "Failed to delete file. Error:2"

I've set debug on than deleted file from flash and than wrote defaul config file:

```
12:10:12.581 -> bmp@ble_micro_pro>Match key: "config"
12:11:05.056 -> <info> CLOCK: Update config
12:11:05.056 -> <info> CLOCK: Received json
12:11:05.056 -> <info> app: Create file
12:11:05.056 -> <info> app: Failed to write. Error:2

```

I've tried to delete config files from CLI:

```
11:53:47.670 -> bmp@ble_micro_pro>remove 0
11:53:51.969 -> <error> app: Failed to delete file. Error:2
```

```
11:57:21.665 -> bmp@ble_micro_pro>remove 1
11:57:41.024 -> <error> app: Failed to delete file. Error:2
```

Here some logs from CLI:

```
11:57:41.024 -> bmp@ble_micro_pro>ee show
11:57:54.275 -> show eeprom
11:57:54.275 -> ec fe 00 00 00 00 00 ff
11:57:54.275 -> 03 00 ff ff 00 00 00 00
11:57:54.275 -> 00 00 00 00 00 00 00 00
11:57:54.275 -> 00 00 00 00 00 00 00 00
11:57:54.275 -> bmp@ble_micro_pro>
```

INFO_UF2.TXT
```
UF2 Bootloader v0.7.0-0-g3857510
Model: BLE Micro Pro
Board-ID: NRF52840-BMP-V1
API version: 9
Config version: 2
```

VERSON.TXT

```
API version: 9
Config version: 2
Build from: bmp-0.7.0-0-g19d009e81
Build Target: ble_micro_pro_default
```
CONFIG.JSN (From flash)

```
{"config":{"version":2,
"device_info":{"vid":"0x0000","pid":"0x0000","name":"ble_micro_pro","manufacture":"sekigon-gonnoc","description":"A development board for wireless split keyboards"},
"matrix":{"rows":1,"cols":19,"device_rows":1,"device_cols":19,"debounce":1,"is_left_hand":1,"diode_direction":0,"row_pins":[33],"col_pins":[1,2,5,6,7,8,9,10,11,12,13,14,15,16,17,18,19,20,22],
"layout":[
  1,  2,  3,  4,  5,  6,  7,  8,  9, 10, 11, 12, 13, 14, 15, 16, 17, 18]},
"mode":"SINGLE","startup":0,
"peripheral":{"max_interval":60,"min_interval":30,"slave_latency":7},
"central":{"max_interval":60,"min_interval":30,"slave_latency":7},
"led":{"pin":255,"num":128},
"keymap":{"locale":"US","use_ascii":0},
"reserved":[0,0,0,0,0,0,0,0]}}
```

KEYMAP.JSN (From flash)
```
{"keyboard":"ble_micro_pro",
"keymap":"",
"layout":"LAYOUT",
"layers":
[["KC_A","KC_B","KC_C","KC_D","KC_E","KC_F","KC_G","KC_H","KC_I","KC_J","KC_K","KC_L","KC_M","KC_N","KC_O","KC_P","KC_Q","KC_R"],

["KC_S","KC_NO","KC_NO","KC_NO","KC_NO","KC_NO","KC_NO","KC_NO","KC_NO","KC_NO","KC_NO","KC_NO","KC_NO","KC_NO","KC_NO","KC_NO","KC_NO","KC_NO"]]}

```

sekigon-gonnoc, 2020-06-13:
I have never seen this error. It seems I need modify bootloader so please give me some time to investigate

sekigon-gonnoc, 2020-06-13:
Could you try bootloader in this zip? (Raw UF2 file is not uploadable in issue page)
[ble_micro_pro_bootloader_0_7_0-1.uf2.zip](https://github.com/sekigon-gonnoc/BLE-Micro-Pro/files/4774805/ble_micro_pro_bootloader_0_7_0-1.uf2.zip)

azat-dev, 2020-06-13:
Wow, thank you for so fast reply 🥇  It's a live now!

Here is some logs after update:
```

22:39:36.618 -> bmp@ble_micro_pro>debug on
22:39:42.274 -> bmp@ble_micro_pro>Match key: "config"
22:40:38.402 -> <info> CLOCK: Update config
22:40:38.402 -> <info> CLOCK: Received json
22:40:38.402 -> <info> app: Create file
22:40:38.402 -> <info> app: Write succeed
22:41:36.429 -> Match key: "layers"
22:41:36.429 -> Update keymap. length:300
22:41:36.429 -> 1 extended keycodes are found
22:41:36.429 -> keyboard:kyria/rev1:LAYOUT
22:41:36.429 -> <info> CLOCK: Received json
22:41:36.466 -> <info> app: Create file
22:41:36.466 -> <info> app: Write succeed
22:41:36.466 -> <info> app: No file was found
22:41:36.466 -> <info> app: Create file
22:41:36.466 -> <info> app: Write succeed
22:41:36.466 -> <info> app: No file was found

22:44:34.275 -> ee show
22:44:34.275 -> show eeprom
22:44:34.275 -> ec fe 00 00 00 00 00 ff
22:44:34.275 -> 03 00 ff ff 00 00 00 00
22:44:34.275 -> 00 00 00 00 00 00 00 00
22:44:34.275 -> 00 00 00 00 00 00 00 00
```

Closed 2020-06-13.

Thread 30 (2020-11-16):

QMK ConfiguratorでWebSerial経由のキーマップ書き込みした場合に拡張キーコードが保存されない場合がある

sekigon-gonnoc, 2020-11-16:
- ブラウザに依存？
  - ChromeではなくVivaldiを使った場合に発生？
  - Chromeを使ったところ保存されるようになった
  - 以降はVivaldiでも発生していない

##  暫定対策
- Chromeの使用を推奨する
- それでも上手くいかない倍はjsonファイルをダウンロードして直接コピーする

https://discord.com/channels/376937950409392130/508485002170990602/777864233705537577

sekigon-gonnoc, 2021-07-27:
- v0.10.0で対策。様子見

Closed 2021-07-27.

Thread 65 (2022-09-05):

config_converterでlayoutのdefineがtype aliasの場合にパースに失敗する

k-omotani, 2022-09-05:
Keyball61のconfigをconvertしようとして発見
このパターンのようにdefineとしてaliasで定義されている場合、`elif '#define ' + self.search_layout + '(' in string:`のパターンに入らずに`ERROR: Failed to find`になります。
```
#define LAYOUT_right_ball( \
...
    }

#define LAYOUT LAYOUT_right_ball
```
https://github.com/Yowkees/keyball/blob/main/qmk_firmware/keyboards/keyball/keyball61/keyball61.h

error log
```
$ ./BLE-Micro-Pro/AboutDefaultFirmware/keyboards/config_converter.py ./keyball/qmk_firmware/keyboards/keyball/keyball61

 ** Making config.json from ./keyball/qmk_firmware/keyboards/keyball/keyball61 **
0: LAYOUT_right_ball		keyball/keyball61/keyball61.h:26
1: LAYOUT_left_ball		keyball/keyball61/keyball61.h:46
2: LAYOUT_dual_ball		keyball/keyball61/keyball61.h:66
3: LAYOUT_no_ball		keyball/keyball61/keyball61.h:86
4: LAYOUT		keyball/keyball61/keyball61.h:108
5: LAYOUT_universal		keyball/keyball61/keyball61.h:109

Use layout: 4
ERROR: Failed to find LAYOUT
This keyboard is split keyboard
warning: MATRIX len and PINS len do not match in both row and col.
```

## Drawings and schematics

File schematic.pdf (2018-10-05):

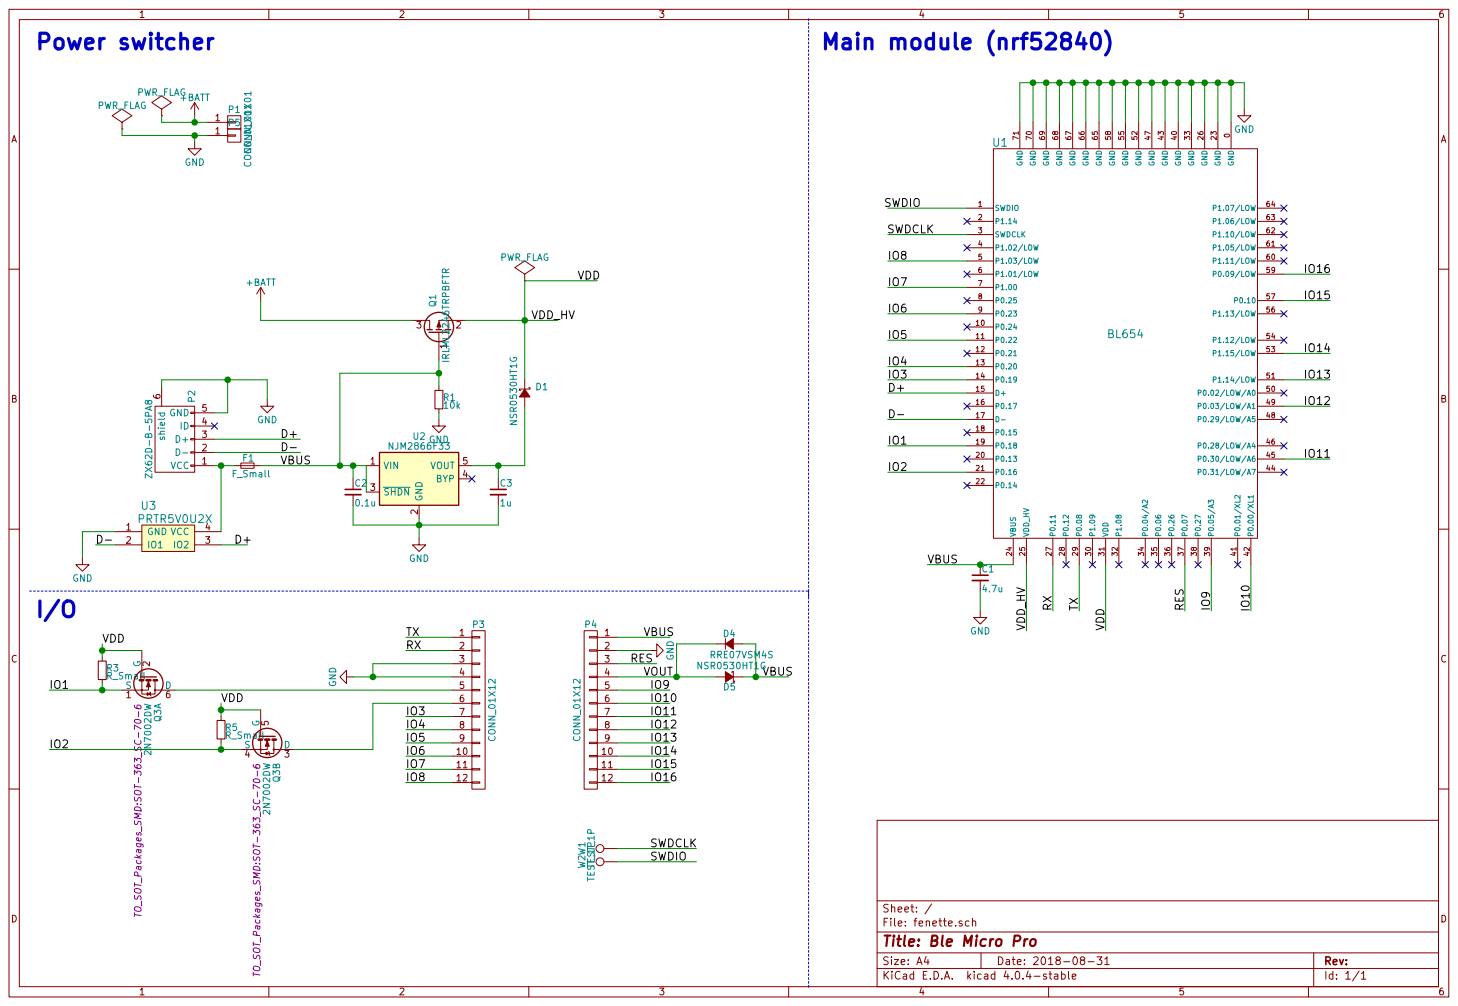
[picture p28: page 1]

0 SWDIO 1 P1.14 2 SWDCLK 3 P1.02/LOW 4 P1.03/LOW 5 P1.01/LOW 6 P1.00 7 P0.25 8 P0.23 9 P0.24 10 P0.13 20 P1.09 30 GND 40 P0.02/LOW/A0 50 P1.11/LOW 60 GND 70 P0.22 11 P0.16 21 VDD 31 P0.01/XL2 41 P1.14/LOW 51 P1.05/LOW 61 GND 71 P0.21 12 P0.14 22 P1.08 32 P0.00/XL1 42 GND 52 P1.10/LOW 62 P0.20 13 GND 23 GND 33 GND 43 P1.15/LOW 53 P1.06/LOW 63 P0.19 14 VBUS 24 P0.04/A2 34 P0.31/LOW/A7 44 P1.12/LOW 54 P1.07/LOW 64 D+ 15 VDD_HV 25 P0.06 35 P0.30/LOW/A6 45 GND 55 GND 65 P0.17 16 GND 26 P0.26 36 P0.28/LOW/A4 46 P1.13/LOW 56 GND 66 D- 17 P0.11 27 P0.07 37 GND 47 P0.10 57 GND 67 P0.15 18 P0.12 28 P0.27 38 P0.29/LOW/A5 48 GND 58 GND 68 P0.18 19 P0.08 29 P0.05/A3 39 P0.03/LOW/A1 49 P0.09/LOW 59 GND 69 U1 BL654 GND

File: fenette.sch Sheet: /
Id: 1/1 Title: Ble Micro Pro

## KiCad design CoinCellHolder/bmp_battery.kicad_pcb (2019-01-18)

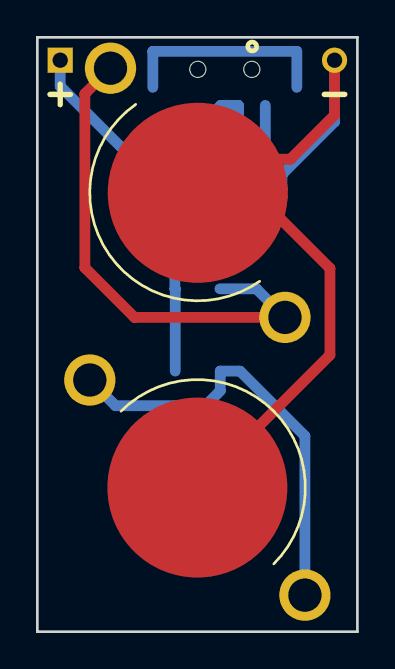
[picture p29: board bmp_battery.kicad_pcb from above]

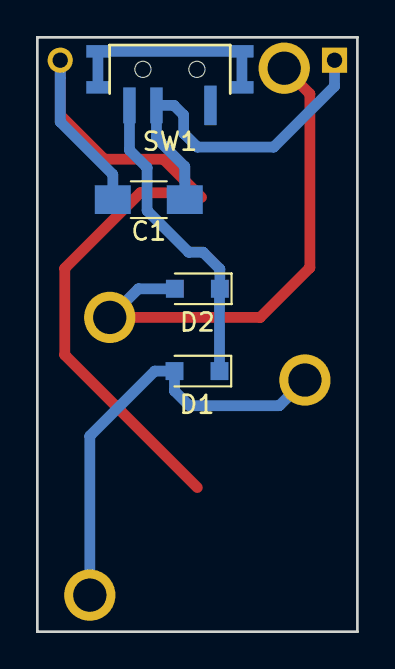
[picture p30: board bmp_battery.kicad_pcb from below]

Board: 2 copper layers, 17.8 x 33.0 mm, 8 parts (4 on the bottom side), 5 nets.

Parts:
BT1, BT2: Battery; ali_CR1632
C1: C_Small; C_1206_HandSoldering
D1, D2: D_Schottky_Small; D_SOD-323_HandSoldering
P1, P2: CONN_01X01; Pin_Header_Straight_1x01_Pitch2.54mm
SW1: SWITCH_INV; MK12C02

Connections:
GND: BT1.2, BT2.2, C1.2, P2.1
unnamed: BT1.1, D1.2
unnamed: BT2.1, D2.2
unnamed: C1.1, P1.1, SW1.2
unnamed: D1.1, D2.1, SW1.3

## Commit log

2018-11-03 電池ホルダの説明を追加
2019-01-18 Add KiCad files of CoinCellHolder
    [bmp_battery.kicad_pcb, bmp_battery.sch]
2019-09-16 #5 ビルドに関する記述を修正
2019-09-28 uf2ビルドオプションについて
2019-10-12 変換時にレイアウトを選べるようにした
2019-10-12 Ergodashのレイアウトを追加
2019-10-22 [fix]Layout選択時の行数がずれていたのを修正
2019-10-28 スプリットキーボードのコンフィグ変換時にlpme用の設定を生成
2019-10-31 Fix error: 変換スクリプトのインデントがずれていたのを修正
2019-11-20 Add Keyboard Naked60/64 (#11)
    * Add Keyboard Naked60/64
    各キーボードのdefaultとsalicylicのconfigとkeymapを追加
    * Keymap Update
    一部のキーコードが間違っていた修正
    * Keymap Update Naked60 / 64
    ・Naked60のピンをシングルに変更
    ・Naked60/64の全角半角キーをKC_ZHTGに変更
    ・ALT_TをLALT_Tに変更
2019-11-21 Add keyboard 7sKB (#12)
    キーボード7sKBの以下のファイルを追加します。
    ・左右無線型、及びTRRS接続型のConfig
    ・USのdefaultマップ、及びJPのsalicylicマップ
2020-04-10 変換スクリプトを修正
2020-06-21 Add keyboard JISplit89 (#21)
    ・左右無線型のConfig
    ・JPのdefaultマップ
    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
2020-06-22 Update jisplit89_rev1_default.json (#22)
    キーマップの一部をコンフィギュレータに合わせて修正
2020-06-28 Claw44 fix cols (#23)
2020-07-12 ハードウェアの準備に情報を追加した
    なんか気になったので書いた
2020-07-17 コンスルーのピン数に関する記述を修正
2020-09-05 Update design_guide.md
    NeoPixel系LEDの駆動に使えるピンについて記載
2020-11-13 AJisai74と7sPlusの追加及び微更新(2回目) (#29)
    ■キーボード追加
    ・AJisai74
    ・7sPlus
    ■キーマップ更新
    ・JISplit89
    ・7sKB
2020-11-29 uf2フォーマットのファームウェアによる書き込み方法を詳細化
2021-02-09 ErgoArrowsの追加
    以下のファイルを追加します。
    ergoarrows_lpme_left_config.json
    ergoarrows_master_left_config.json
    ergoarrows_slave_right_config.json
    ergoarrows_default.json
2021-03-27 7sKB,JISplit89のVID/PID更新
    Remap対応のため7sKBとJISplit89をQMK側に合わせます。
2021-05-28 add wings42
2021-05-28 Update VID/PID for bat43
2021-08-04 誤字修正
2021-08-04 空白があるとリンクにならなかったので見出しを変更
2021-09-14 Change Lily58 VID PID
2021-10-05 Add Keyboard GL516
    GL516の三種を追加
    ・A52GL
    ・J73GL
    ・N51GL
2021-10-05 Naked48/60のVID/PIDを変更
    Naked48とNaked60のVID/PIDを変更します。
2021-10-11 PistachioMacroPadのVID/PIDを更新
2021-11-28 KeyFuda01_Tenkeyを追加
    設定ファイル：keyfuda01_tenkey.json
    初期キーマップファイル：keyfuda01_tenkey_default.json
2021-12-05 KeyFuda02_mediaを追加
2022-04-01 config.jsonの解説にstartupの項目を追加
2022-05-08 キーマップを変更
2022-06-18 キーマップを修正
2022-06-18 名前を変更
2022-06-18 右下のキー
2022-06-18 キーマップを追加
2022-06-18 USの左下を修正
2022-07-24 KeyFuda03_Stickの追加
2022-07-24 KeyFuda04の追加
2022-08-05 C48GLとO50GLの追加
2022-09-04 式で定義されたcol_num, row_numも扱えるように修正
2022-12-08 guide68の追加
2023-02-20 ロータリーエンコーダをRemapで変更できるように修正
    ロータリーエンコーダをRemapから変更できるように修正しました
2023-02-20 （KeyFuda03）ロータリーエンコーダをRemapで変更できるように修正
    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
2023-11-02 bmp-vial関連のファイルを追加
2023-11-10 アップロード
2024-03-17 KeyFuda02 and 03 added to new firmware
    I have finished verifying my KeyFuda02 and KeyFuda03 to the new firmware and will update them.
    I have confirmed that the change operation is possible with Remap.
    KeyFuda02とKeyFuda03の新しいファームウェアへの検証が終わったので更新します。
    Remapで変更操作が可能であることを確認しています。
2024-05-29 KeyFuda01と04を追加
    KeyFuda01 TenkeyPad
    KeyFuda04 GridPad
    以上2つのマクロパッドの追加です。
    検証済みです。
2024-10-22 ファイル名規則が異なっていたため修正
    なぜかBLE Micro Pro Web ConfiguratorでKeyFuda01の設定を書き込めなかった（404が出る）ので調べたらファイル名規則が違ったので修正します。
    Salicylic-acid3
    ↓
    salicylic_acid3
2024-11-26 7sProMaxを追加
2025-01-16 古い設定ファイル
2025-01-16 Palmslaveのbmp-vial-config
2025-01-16 Revert "古い設定ファイル"
    This reverts commit 117097a3558021344d81cf58e09850657ee1ec70.
2025-01-16 デフォルトのキーマップ
2025-01-18 デフォルトのキーマップを変更しました。
2025-05-14 キーマップの無線経由書き換えの説明を追加
2025-06-11 7sPro ELの追加
    7sPro ELを追加します。
    マスター、スレーブ、LPME-IOのコンフィグファイルを追加します。
2025-06-14 Vialのコンフィグファイルの追加
    7sPro ELのVial用コンフィグファイルを追加します。
    前回のPRで漏れていましたので追加します。
2025-07-11 BMP Boostの説明を更新
2026-07-08 DRESSTHINGを追加
    DRESSTHINGのVial設定を追加します。
    実機で動作検証済みです。
2026-07-08 DRESSTHING Twinsを追加
    DRESSTHING TwinsのVial設定を追加します。
    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
2026-08-06 Fix DRESSTHING Twins default keymap (previous fix was lost to a filename case mismatch)
